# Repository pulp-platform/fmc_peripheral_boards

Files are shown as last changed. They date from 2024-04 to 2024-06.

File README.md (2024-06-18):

# FMC Peripheral Board

# Introduction

This repository contains the work on the FMC Peripheral boards, which are a set of PCB designs specifically created for validating peripherals on various FPGA platforms enhanced with the FPGA Mezzanine Card (FMC) standard.

In this repository, you will find source files and PDF schematics for a series of these PCB designs. These boards were developed with the specific purpose of facilitating peripheral verification of System on Chip (SoC) designs. We have put significant effort into ensuring these designs are robust and versatile, making them valuable tools for engineers who need to validate and test FPGA interfaces and achieve seamless integration with a wide range of peripheral devices. Moreover, thanks to the modularity of theese designs we have been able to test peripherals on silicon proven SoC managing to use the same hardware in the loop along the entire design process. By providing these resources, we aim to support the development and testing processes, allowing for more generic and broad applications.

Ideal for hardware developers and testers, these designs facilitate accurate and efficient verification processes, enhancing reliability and performance.

We have designed these PCBs to the best of our ability and they have performed well for us. However we offer no warranty of any kind (see also LICENSE) and provide these as is, without any support, use at your own risk.

# License

The files provided in this repository are released under Creative Commons with Attribution (`CC-BY`) (see `LICENSE` for details) license, except for `04_Expansion_Modules/USART_Module/fw/` that contains third-party source files that come from STMicroelectronics and has been released under Berkeley Software Distribution 3-Clause (`BSD 3-Clause`) license (see `04_Expansion_Modules/USART_Module/fw/LICENSE` for details).

# Structure of the repository

This repository contains the following folders:

- **`01_Carrier_Board`**
    - The described FMC (FPGA Mezzanine Card) Carrier board is designed to enhance FPGA development platforms by adding essential peripheral interfaces. This board is tailored for developers looking to experiment with and implement storage and audio functionalities in their FPGA projects.

    **Features of the FMC Board:**

    1. **Hyper Flash:**<br>
    The Hyper Flash provides high-speed non-volatile memory storage, ideal for applications requiring fast read and write operations with a high level of endurance. This makes it suitable for high-performance data buffering or quick-boot applications.

    2. **SPI Flash:**<br>
    The SPI Flash memory is included for reliable, low-latency access, serving as an excellent resource for storing firmware or small application codes in embedded systems. Its SPI interface ensures compatibility with a vast array of FPGA boards.

    3. **I2C EEPROM:**<br>
    Equipped with I2C EEPROM, this board offers a modest amount of memory but with very low power consumption, perfect for storing configuration settings or small amounts of data that must persist through power cycles, such as device calibration data or user preferences.

    4. **2x Microphones:**<br>
    The inclusion of two microphones allows for audio input and recording capabilities. This feature is especially useful for applications involving sound capture, voice command recognition, or environmental noise analysis. The dual setup can also support stereo audio recording or be used for advanced processing techniques like beamforming or noise reduction.

    **Design and Connectivity:**<br>
    The board is designed to conform to the FMC standard, ensuring it can be used with FMC-compatible FPGA development boards. It provides a high-pin-count (HPC) connector which allows it to interface seamlessly with the host FPGA, supporting high throughput and multiple I/O options.
    The board exposes 2x M.2 type E expansion connectors which allow to connect Expansion Module specifically designed for different targets

- **`02_FMC_Test_Module`**
    - The FMC test module described here is specifically designed for enhanced debugging and signal analysis.
    It can be attached directly on top of the carrier board to monitor and probe signals interfacing with various peripherals. It can also be configured to function as a GPIO (General Purpose Input/Output) expansion when connected directly to an FPGA, providing additional flexibility in signal management and control.

- **`03_Example_Module`**
    - This folder contains a design example of an M.2 type E expansion module

- **`04_Expansion_Modules`**
    - This folder contains the design of the following M.2 type E expansion modules

        - **`Ethernet_Module`**
            - The M.2 type E module described is a specialized network interface card (NIC) that incorporates Ethernet functionalities, specifically designed to fit into compact and modular systems. This module provides Ethernet connectivity via an RJ45 connector and features the RTL8211E-VL-CG Ethernet PHY transceiver, which supports various Ethernet standards including 10Base-T, 100Base-TX, and 1000Base-T as specified by the IEEE 802.3 standards.
            For data communication between the MAC (Media Access Control) layer and the PHY (Physical Layer), the module supports both RGMII (Reduced Gigabit Media Independent Interface) and GMII (Gigabit Media Independent Interface). RGMII is used for more compact and reduced pin count requirements, suitable for high-speed data operations at 1000Base-T, while GMII is applicable for full gigabit media independent data handling, including 1000Base-T, 10Base-T, and 100Base-TX.

        - **`PWM_Module`**
            - The M.2 type module described is an innovative expansion card specifically designed to test up to 8xPWM. It exposes four Crazyflie 2.X DC motor connectors which can be dinamically connected to all the PWM outputs.

        - **`USART_Module`**
            - The M.2 type module designed for communication with the STM32L412K8T6 microcontroller using the USART (Universal Synchronous/Asynchronous Receiver/Transmitter) protocol is a specialized interface card. This module serves as a bridge to facilitate robust serial communication between the design mapped on the FPGA and the onboard STM32L412K8T6 microcontroller. This folder is organized as follows:
               - `fw/`, directory contains source code dedicated to testing the USART functionality. To generate the complete software stack for the STM32L412K8T6 microcontroller, you can use the STM32 CubeMX Tool provided by STMicroelectronics (https://www.st.com/content/st_com/en/stm32cubemx.html#st-get-software) and configure its pinout accordingly to the schematic under `hw/Documentation/UART_Module_SCH.PDF`
               - `hw/`, directory contains the Altium designer source files and PDF schematics of the USART_Module

        - **`uSD_Module`**
            - The M.2 type module described is an innovative expansion card that facilitate the development, testing, and debugging of Secure Digital Input Output (SDIO) protocol implementations, allowing engineers to easily interface with microSD cards and ensure compliance with SDIO standards.

- **`05_FMC_4_Hyperram_32MB`**
    - The FMC board described here is a specialized module designed to significantly enhance the memory capabilities.
    It features four 8MB HyperRAMs, providing a total of 32MB of additional low-pin-count RAM. 

# Publications

If you use these PCBs in your work, please cite us:

```
@INPROCEEDINGS{9607006,
  author={Valente, Luca and Rossi, Davide and Benini, Luca},
  booktitle={2021 IFIP/IEEE 29th International Conference on Very Large Scale Integration (VLSI-SoC)}, 
  title={Hardware-In-The Loop Emulation for Agile Co-Design of Parallel Ultra-Low Power IoT Processors}, 
  year={2021},
  volume={},
  number={},
  pages={1-6},
  keywords={Program processors;Computational modeling;Emulation;Very large scale integration;Tools;Performance analysis;Sensors;Verification;FPGA emulation;IoT;CNN},
  doi={10.1109/VLSI-SoC53125.2021.9607006}}
```

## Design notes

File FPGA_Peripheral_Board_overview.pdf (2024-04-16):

# FPGA Peripheral Board

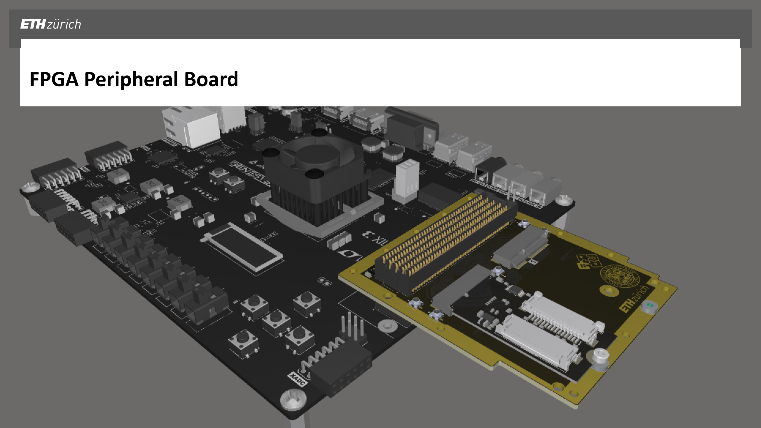
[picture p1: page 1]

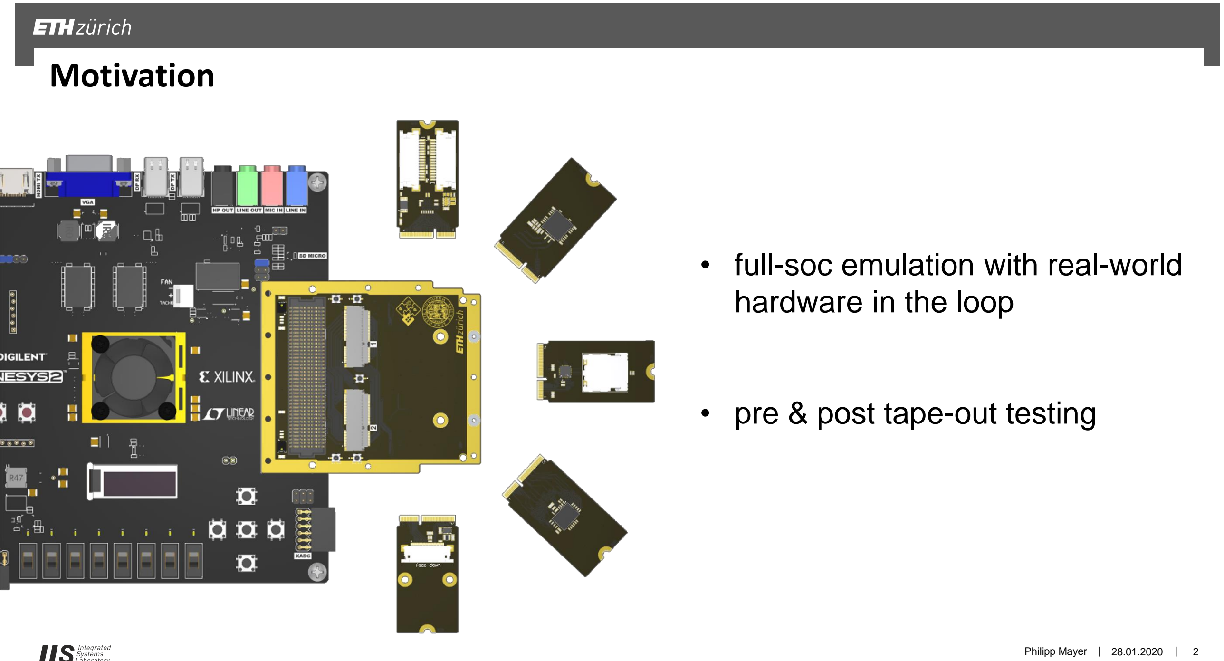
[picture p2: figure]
Philipp Mayer | 28.01.2020; Motivation; • full-soc emulation with real-world hardware in the loop; • pre & post tape-out testing

# Overview

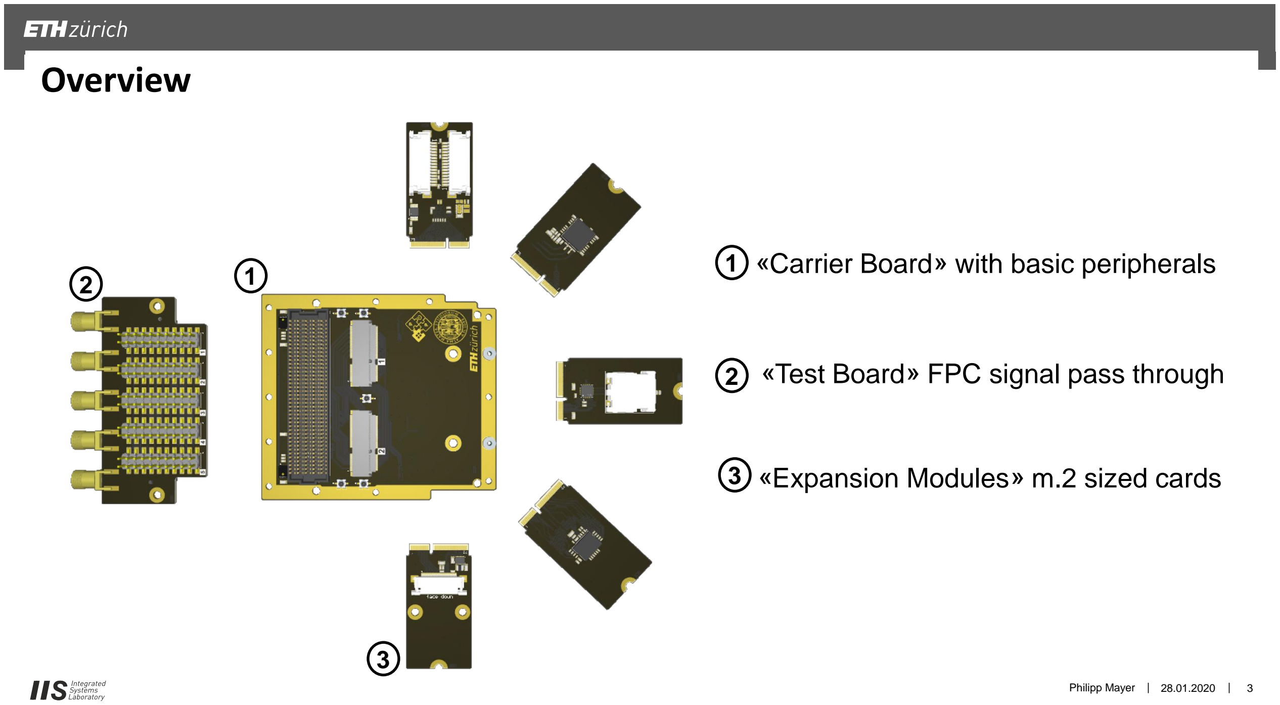
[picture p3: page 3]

# «Carrier Board» with basic peripherals 1

3

2

# «Test Board» FPC signal pass through

# «Expansion Modules» m.2 sized cards

1

2

3

# Block Diagram

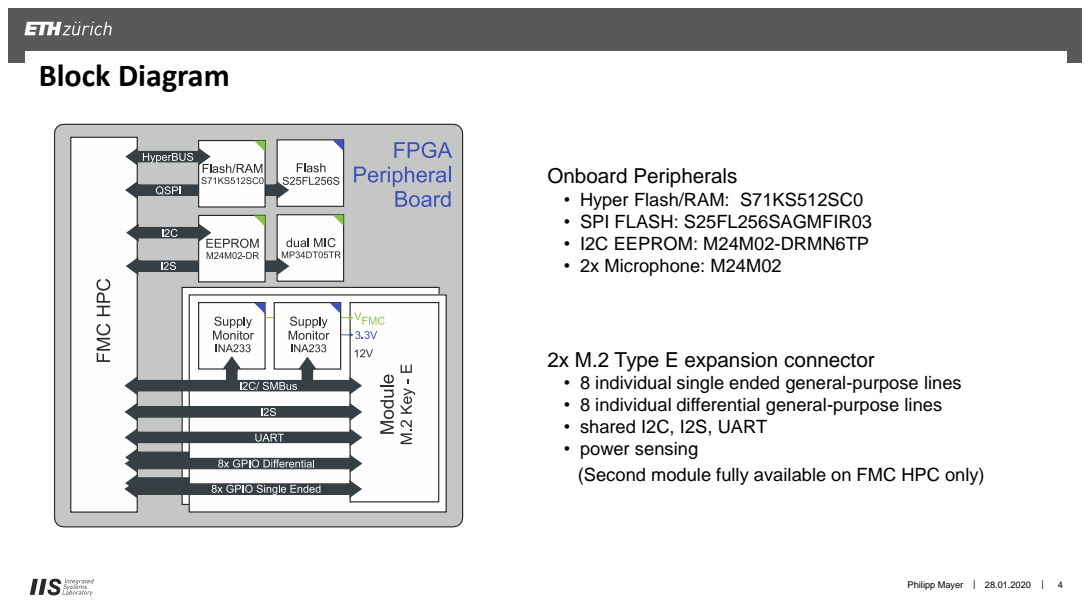
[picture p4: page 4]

Onboard Peripherals
• Hyper Flash/RAM: S71KS512SC0
• SPI FLASH: S25FL256SAGMFIR03
• I2C EEPROM: M24M02-DRMN6TP
• 2x Microphone: M24M02

2x M.2 Type E expansion connector
• 8 individual single ended general-purpose lines
• 8 individual differential general-purpose lines
• shared I2C, I2S, UART
• power sensing
(Second module fully available on FMC HPC only)

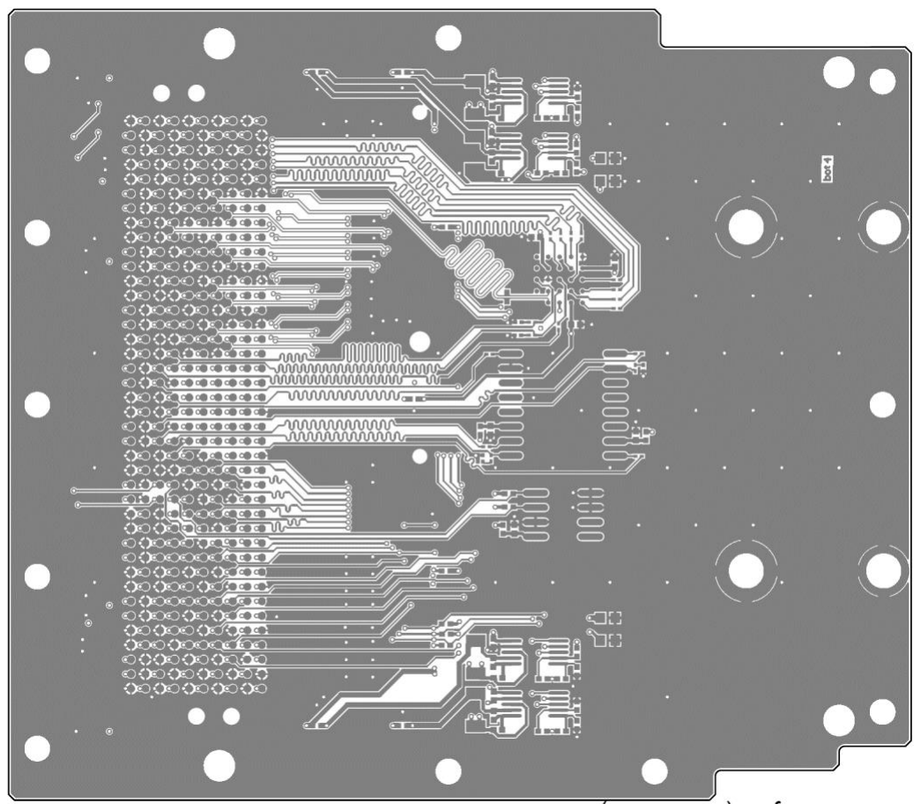
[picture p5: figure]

Signal Class | Routed Length | Delay Tolerance
HyperBUS | ~65 mm | 50 ps
QSPI | ~45 mm | 100 ps
CON1_GP_D[0..7 | ~50 mm | 50 ps
CON1_GP_S[0..7] | ~15 mm | 5 ps
CON2_GP_D[0..7] | ~14 mm | 50 ps
CON2_GP_S[0..7] | ~30 mm | 5 ps

# Only length matched

# in same signal group !

# Power Measurements

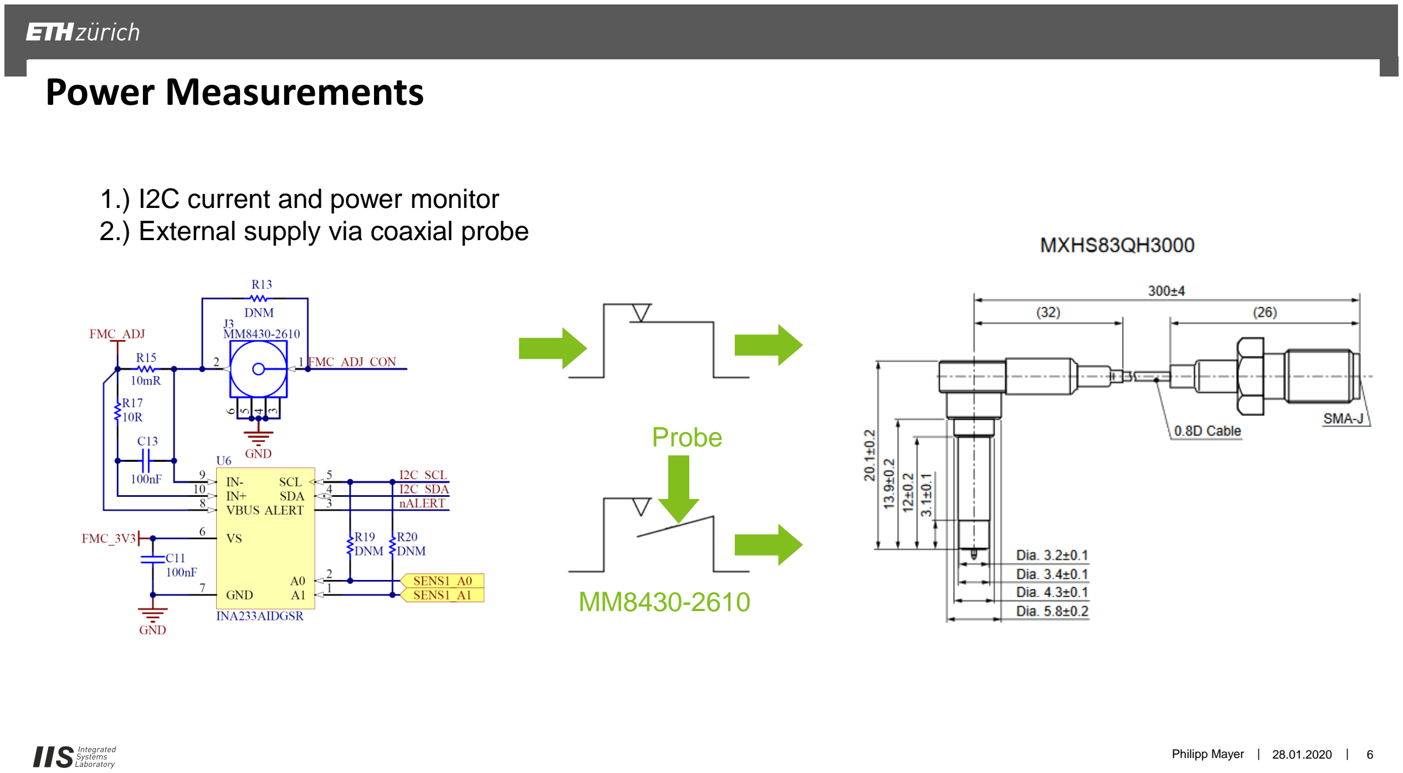
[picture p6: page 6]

# 1.) I2C current and power monitor 2.) External supply via coaxial probe

# Probe

MM8430-2610

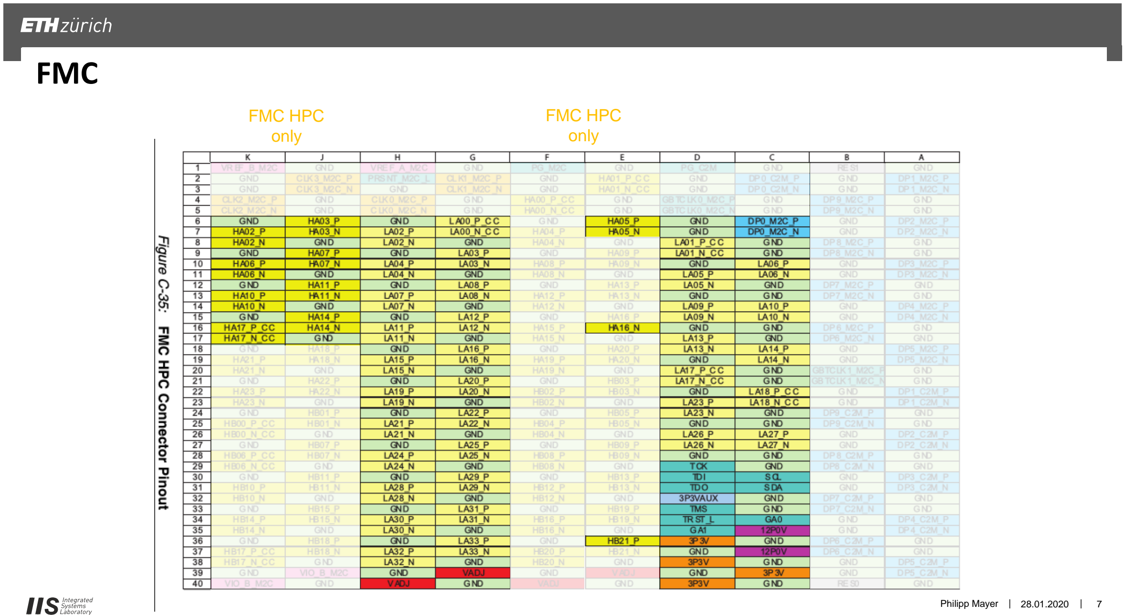
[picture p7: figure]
FMC; FMC HPC only

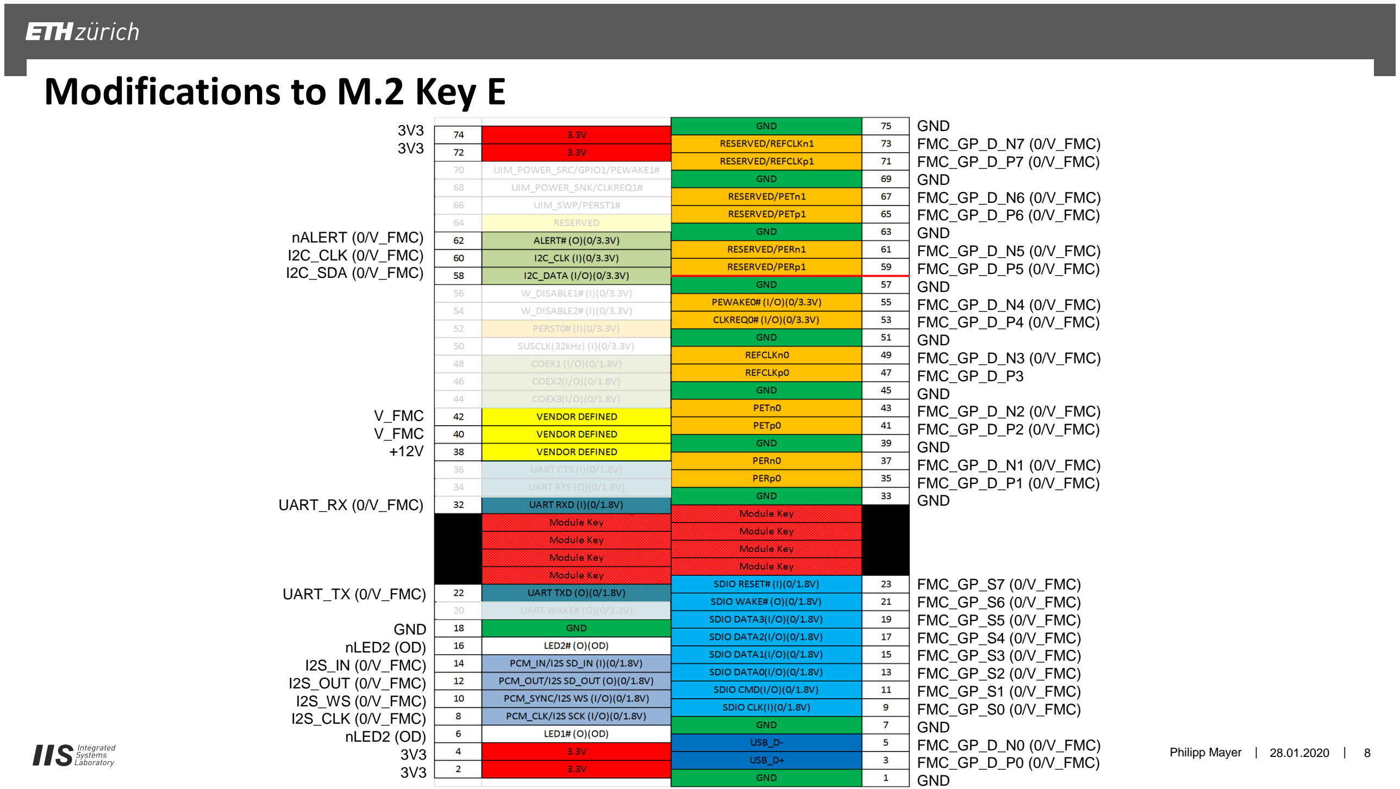
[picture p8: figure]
Modifications to M.2 Key E; GND FMC_GP_D_N7 (0/V_FMC) FMC_GP_D_P7 (0/V_FMC) GND FMC_GP_D_N6 (0/V_FMC) FMC_GP_D_P6 (0/V_FMC) GND FMC_GP_D_N5 (0/V_FMC) FMC_GP_D_P5 (0/V_FMC) GND FMC_GP_D_N4 (0/V_FMC) FMC_GP_D_P4 (0/V_FMC) GND FMC_GP_D_N3 (0/V_FMC) FMC_GP_D_P3 GND FMC_GP_D_N2 (0/V_FMC) FMC_GP_D_P2 (0/V_FMC) GND FMC_GP_D_N1 (0/V_FMC) FMC_GP_D_P1 (0/V_FMC) GND; FMC_GP_S7 (0/V_FMC) FMC_GP_S6 (0/V_FMC) FMC_GP_S5 (0/V_FMC) FMC_GP_S4 (0/V_FMC) FMC_GP_S3 (0/V_FMC) FMC_GP_S2 (0/V_FMC) FMC_GP_S1 (0/V_FMC) FMC_GP_S0 (0/V_FMC) GND FMC_GP_D_N0 (0/V_FMC) FMC_GP_D_P0 (0/V_FMC) GND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

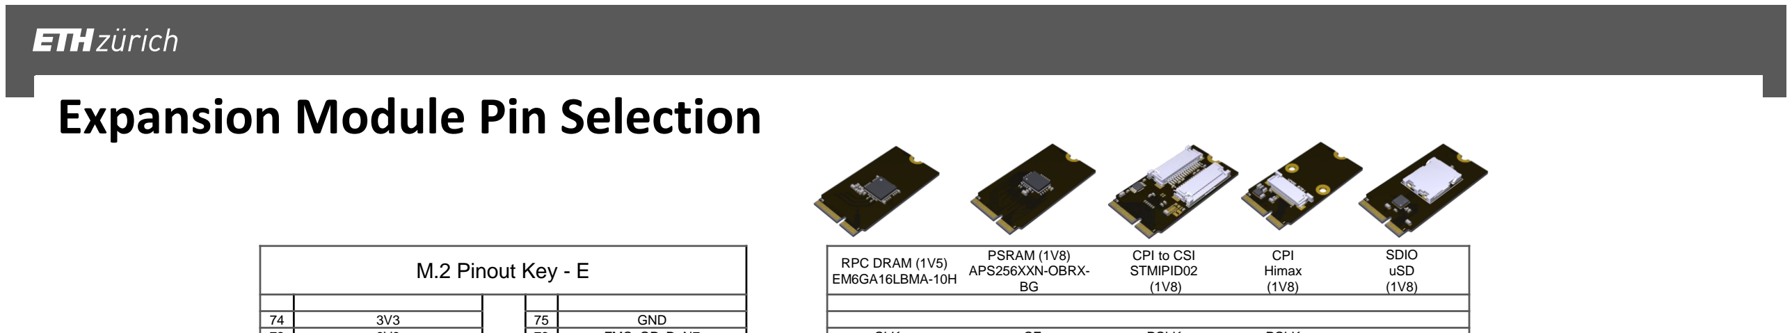
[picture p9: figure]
Expansion Module Pin Selection; M.2 Pinout Key - E; RPC DRAM (1V5) EM6GA16LBMA-10H; PSRAM (1V8) APS256XXN-OBRX- BG; CPI to CSI STMIPID02 (1V8); CPI Himax (1V8); SDIO uSD (1V8); GND

72 | 3V3 | 73 | FMC_GP_D_N7 | CLK_n | nCE | PCLK | PCLK
70 | RESERVED | 71 | FMC_GP_D_P7 | CLK_p | CK | | MCLK
68 | RESERVED | 69 | GND
66 | RESERVED | 67 | FMC_GP_D_N6 | DQS_n | DQS/DM1 | HSYNC | HSYNC
64 | RESERVED | 65 | FMC_GP_D_P6 | DQS_p | DQS/DM0 | VSYNC | VSYNC
62 | nALERT | 63 | GND
60 | I2C_SCL | 61 | FMC_GP_D_N5 | DQS1_n | | | INT
58 | I2C_SDA | 59 | FMC_GP_D_P5 | DQS1_p | | | TRIG
56 | RESERVED | 57 | GND
54 | RESERVED | 55 | FMC_GP_D_N4 | DB15 | DQ15
52 | RESERVED | 53 | FMC_GP_D_P4 | DB14 | DQ14
50 | RESERVED | 51 | GND
48 | RESERVED | 49 | FMC_GP_D_N3 | DB13 | DQ13
46 | RESERVED | 47 | FMC_GP_D_P3 | DB12 | DQ12
44 | RESERVED | 45 | GND
42 | FMC_ADJ (typ 1.8V) | 43 | FMC_GP_D_N2 | DB11 | DQ11 | D11
40 | FMC_ADJ (typ 1.8V) | 41 | FMC_GP_D_P2 | DB10 | DQ10 | D10
38 | FMC_12V | 39 | GND
36 | RESERVED | 37 | FMC_GP_D_N1 | DB9 | DQ9 | D9
34 | RESERVED | 35 | FMC_GP_D_P1 | DB8 | DQ8 | D8
32 | UART_RX | 33 | GND
30 | - | 31 | -
28 | - | 29 | -
26 | - | 27 | -
24 | - | 25 | -
22 | UART_TX | 23 | FMC_GP_S7 | DB7 | ADQ7 | D7 | D7
20 | RESERVED | 21 | FMC_GP_S6 | DB6 | ADQ6 | D6 | D6 | CLK RET
18 | GND | 19 | FMC_GP_S5 | DB5 | ADQ5 | D5 | D5 | SD_D3/nCS
16 | LED2 | 17 | FMC_GP_S4 | DB4 | ADQ4 | D4 | D4 | SD_D2
14 | I2S_IN | 15 | FMC_GP_S3 | DB3 | ADQ3 | D3 | D3 | SD_D1
12 | I2S_OUT | 13 | FMC_GP_S2 | DB2 | ADQ2 | D2 | D2 | SD_D0/MISO
10 | I2S_WS | 11 | FMC_GP_S1 | DB1 | ADQ1 | D1 | D1 | SD_CMD/MOSI
8 | I2S_CLK | 9 | FMC_GP_S0 | DB0 | ADQ0 | D0 | D0 | CLK/SCLK
6 | LED1 | 7 | GND
4 | 3V3 | 5 | FMC_GP_D_N0 | STB
2 | 3V3 | 3 | FMC_GP_D_P0 | nCS
| | 1 | GND

# * Not designed to reach peak DRAM speed!

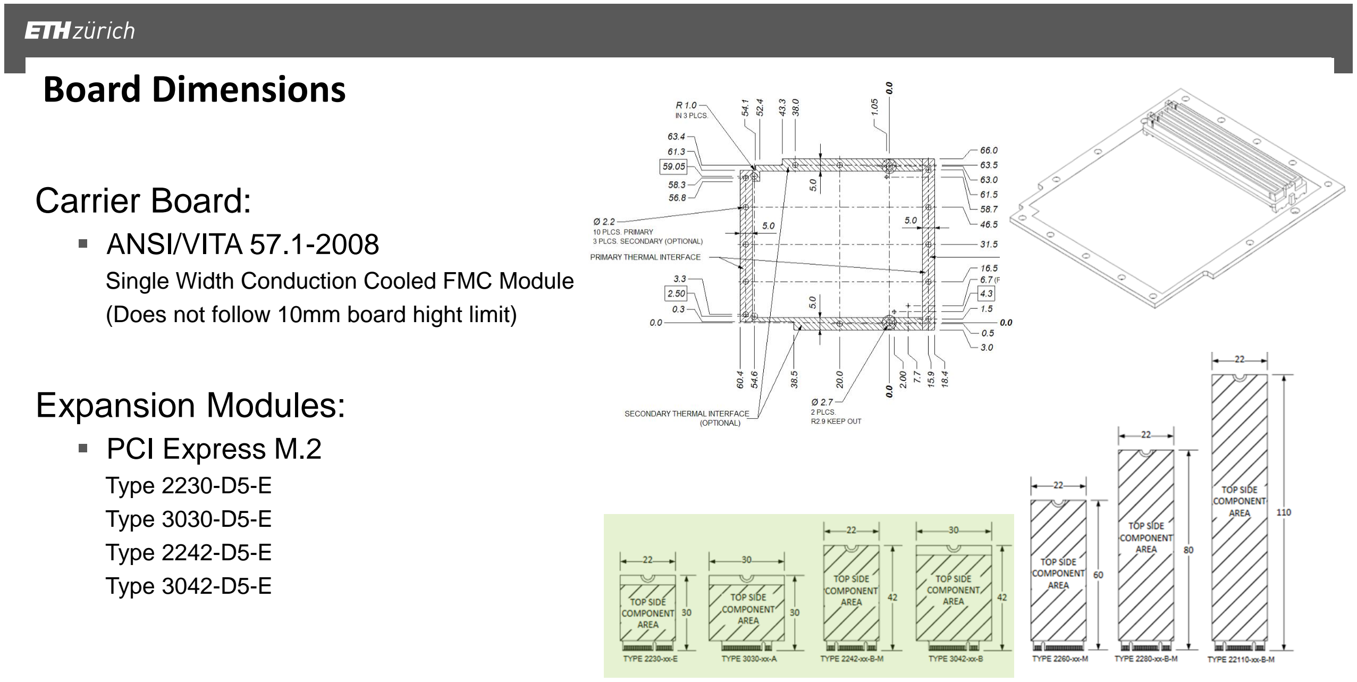
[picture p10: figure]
Board Dimensions; Carrier Board:; ▪ ANSI/VITA 57.1-2008; Expansion Modules:; ▪ PCI Express M.2; Type 2230-D5-E; Type 3030-D5-E; Type 2242-D5-E; Type 3042-D5-E

# Single Width Conduction Cooled FMC Module (Does not follow 10mm board hight limit)

# Documentation

“Conventional” board file | Supporting documentation

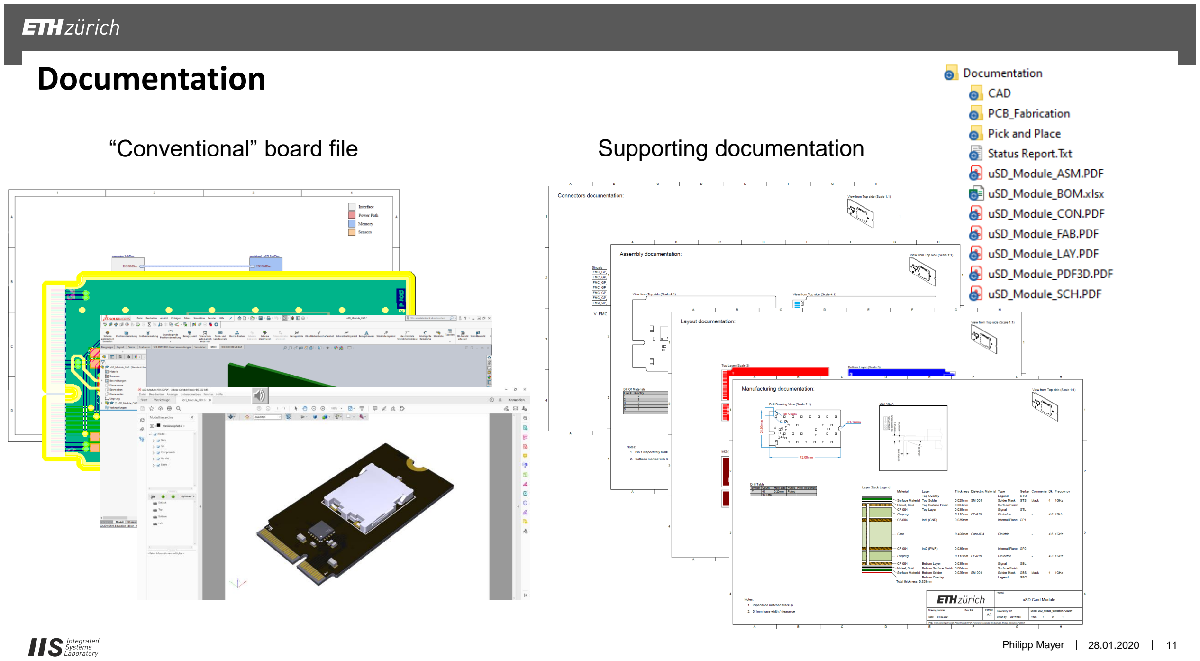
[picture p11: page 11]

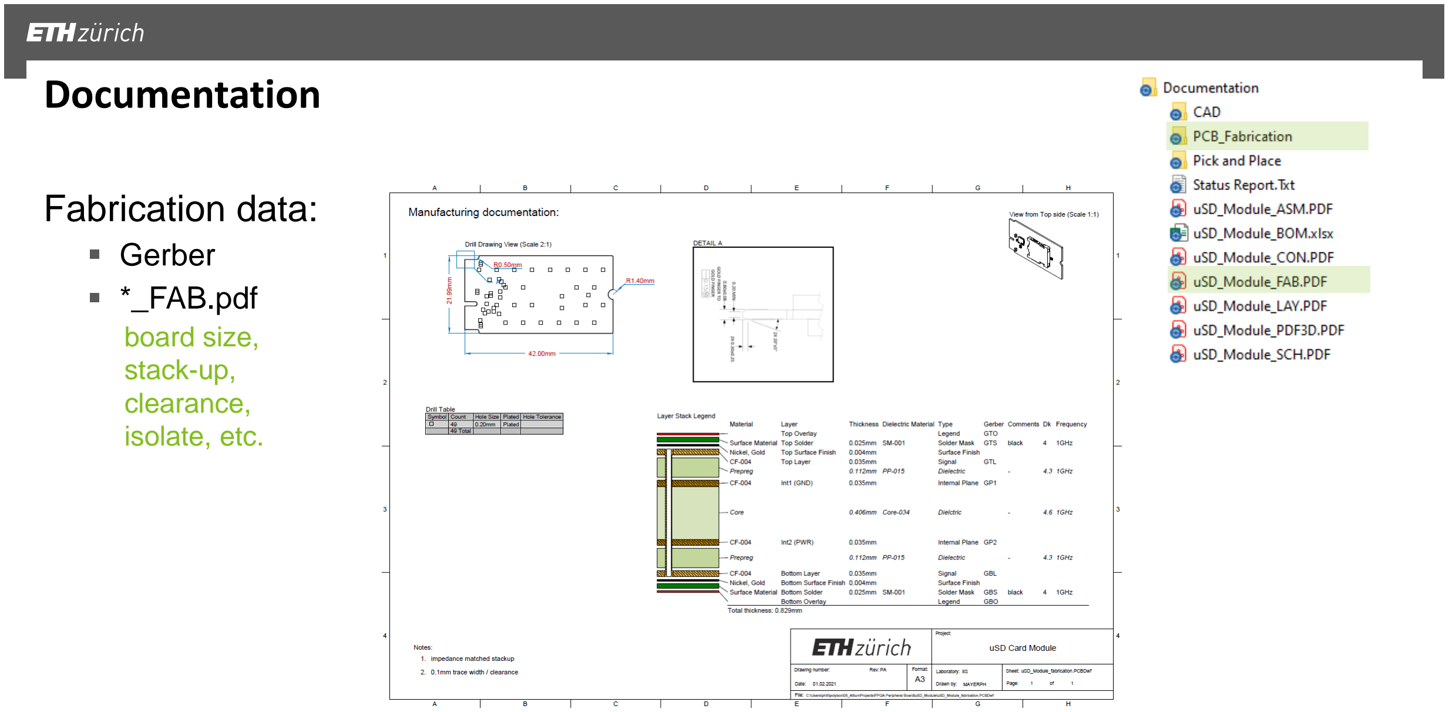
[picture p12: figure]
Fabrication data: ▪ Gerber ▪ *_FAB.pdf; Documentation; board size, stack; -up, clearance, isolate, etc.

Philipp Mayer | 28.01.2020 | 12

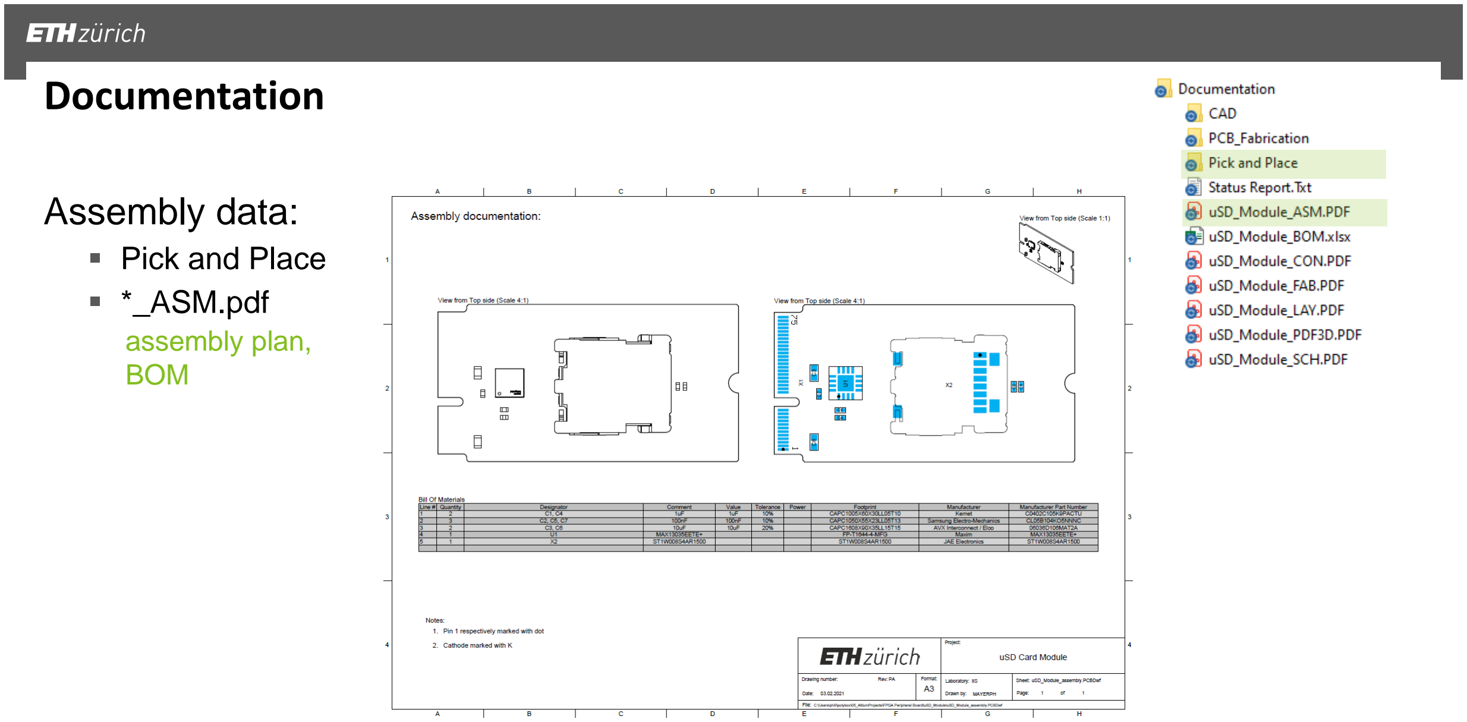
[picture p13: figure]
Assembly data:; ▪ Pick and Place ▪ *_ASM.pdf; Documentation; assembly plan, BOM

Philipp Mayer | 28.01.2020 | 13

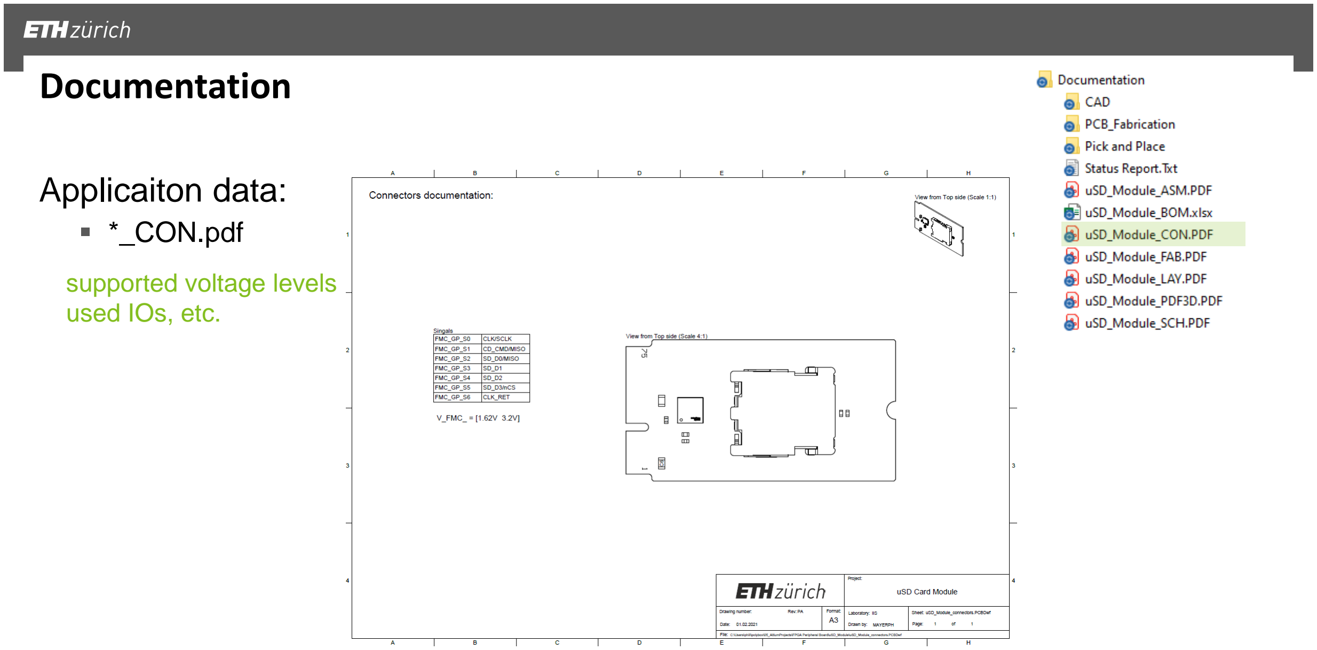
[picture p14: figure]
Applicaiton data:; ▪ *_CON.pdf; Documentation; supported voltage levels used IOs, etc.

Philipp Mayer | 28.01.2020 | 14

# - Modify the “Example Module” project

# Creating a New Module

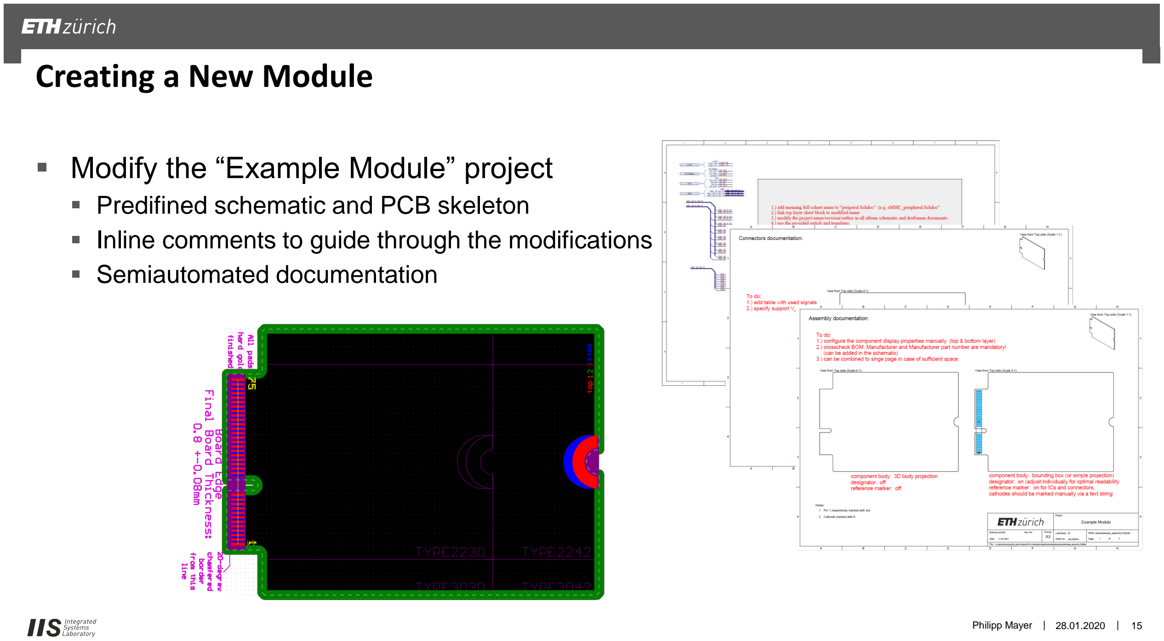
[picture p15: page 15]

# - Predifined schematic and PCB skeleton - Inline comments to guide through the modifications - Semiautomated documentation

Philipp Mayer | 28.01.2020 | 15

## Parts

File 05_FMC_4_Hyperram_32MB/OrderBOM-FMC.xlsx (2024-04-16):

Name | Notes | Description | Designator | Quantity | Manufacturer 1 | Manufacturer Part Number 1 | Supplier 1 | Supplier Part Number 1
ADP1715 |  | IC REG LINEAR 1.8V 500MA 8MSOP | ADP1715 | 1 | Analog Devices Inc | ADP1715ARMZ-1.8-R7 | Digi-key | ADP1715ARMZ-1.8-R7CT-ND
CAP 2.2 µF 25V 1206 (3216) |  | CAP 2.2 µF ±10% 25V X7R 1206 (3216 Metric) Thickness 1.80mm SMD | C13, C15 | 2 | TDK | C3216X7R1E225K160AA | Digi-key | 445-1382-1-ND
CAP 10nF 50V 1206 (3216) |  | CAP 10000pF ±10% 50V CH 1206 (3216 Metric) Thickness 0.75mm SMD | C14 | 1 | TDK | C3216CH1H103K060AA | Digi-key | 445-11579-1-ND
S71KS512SC0 |  | IC 512MB FLASH 64MB DRAM 24FBGA | U1, U2, U3, U4 | 4 | Cypress | S27KS0641DPBHI020 | Mouser | 727-S27KS0641DPBHI02
ASP-134604-01 |  | Conn Array Terminal FMC Male SKT 160 POS 1.27mm Solder ST SMD | J7 | 1 | Samtec | ASP-134604-01 | Digi-key | SAM8732-ND
15K 5% 0603(1608) | Do Not Place | 15K 0.1W 5% 0603 (1608 Metric) SMD | R1 | 1 | Bourns | CR0603-JW-153ELF | Digi-Key | 118-CR0603-JW-153ELFCT-ND
12K 5% 0603(1608) | Do Not Place | 12K 0.1W 5% 0603 (1608 Metric) SMD | R2 | 1 | Bourns | CR0603-JW-123ELF | Digi-Key | 118-CR0603-JW-123ELFCT-ND
CAP 100nF 25V 0603(1608) |  | CAP 100nF 25V ±10% 0603 (1608 Metric) Thickness 1mm SMD | C1, C2, C3, C4, C5, C6, C7, C8, C9, C10, C11, C12 | 12 | TDK | C1608X7R1E104K | Digi-Key | 445-1316-1-ND

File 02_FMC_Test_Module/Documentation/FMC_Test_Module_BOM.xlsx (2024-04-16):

Quantity | Designator | Comment | Value | Tolerance | Power | Footprint | Manufacturer | Manufacturer Part Number
1 | P1 | ASP-134488-01 |  |  |  | BTB-SM1-27-2V400M | Samtec | ASP-134488-01
5 | J1, J2, J3, J4, J5 | CON-SMA-EDGE-S |  |  |  | FP-CON-SMA-EDGE-S-MFG | RF Solutions Ltd. | CON-SMA-EDGE-S
5 | X1, X2, X3, X4, X5 | TSM-110-01-L-DV |  |  |  | SMTC-TSM-110-01-X-DV | Samtec | TSM-110-01-L-DV

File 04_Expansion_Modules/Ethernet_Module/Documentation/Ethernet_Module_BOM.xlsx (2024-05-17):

Quantity | Designator | Comment | Value | Tolerance | Power | Footprint | Manufacturer | Manufacturer Part Number | Supplier 1
3 | C1, C2, C10 | 1uF | 1uF | 10% |  | CAPC1005X60X30LL05T10 | Kemet | C0402C105K9PACTU | Digi-Key
3 | C6, C8, C9 | 10uF | 10uF | 20% |  | CAPC1608X90X35LL15T15 | AVX Interconnect / Elco | 06036D106MAT2A | Digi-Key
4 | C3, C4, C5, C7 | 100nF | 100nF | 10% |  | CAPC1050X55X23LL05T13 | Samsung Electro-Mechanics | CL05B104KO5NNNC | Digi-Key
3 | C11, C13, C14 | 27pF | 27pF | 5% |  | CAPC1005X56X25LL10T15 | KYOCERA AVX | 0402YA270JAT2A | mouser
1 | C12 | 1nF | 1nF | 1% |  | CAPC0603(1608)100_L | Vishay | VJ0603A102FXQCW1BC | mouser
9 | R1, R2, R3, R4 ,R6, R8, R9, R11, R14 | 4.7kR | 4.7kOhm | 1% |  | RESC0603X28X15LL05T05 | Vishay | CRCW02014K70FKED | mouser
1 | R10 | 75 R | 75 Ohm | 1% |  | RESC0603X28X15LL05T05 | Vishay | CRCW020175R0FKED | mouser
1 | R15 | 750 R | 750 Ohm | 1% |  | RESC0603X28X15LL05T05 | Vishay | CRCW0201750RFNED | mouser
1 | R7 | 1.5 kR | 1.5 kOhm | 1% |  | RESC0603X28X15LL05T05 | Vishay | CRCW04021K50FKED | mouser
1 | R13 | 2.49 kR | 2.49 kOhm | 1% |  | RESC0603X28X15LL05T05 | Vishay | CRCW02012K49FKED | mouser
1 | R12 | 1MegR | 1MOhm | 1% |  | RESC0603X28X15LL05T05 | Vishay | CRCW02011M00FKED | mouser
1 | R5 | 0R | 0 Ohm |  |  | RESC1005X40X25LL05T05 | Panasonic | ERJ-2GE0R00X | mouser
1 | LD1 | Yellow LEDs, Vf=1,65V |  |  |  |  | Kingbright | AA3021LSYSK/J3-TR | mouser
1 | LD2 | Red LEDs, Vf=1,8V |  |  |  | LEDC1608X65N | ROHM Semiconducto | CSL1901VW1 | mouser
1 | FB1 | BLM18KG601SN1B | 600Ohm/10MHz |  |  | BLM18EG121SH1D | Murata Electronics | BLM18KG601SN1B | mouser
1 | IC2 | RTL8211E-VL-CG |  |  |  | QFN40P600X600X100-49N |  | RTL8211E-VL-CG
1 | IC1 | LD39015M10R |  |  |  | SOT95P280X145-5N | STMicroelectronics | LD39015M10R | mouser
1 | Y1 | FL2500213Z |  |  |  |  | Diodes Incorporated | FL2500213Z | mouser
1 | J1 | HFJV1-E1G16-L12RL |  |  |  |  | HALO Electronics | HFJV1-E1G16-L12RL | mouser
2 | J2, J3 | HTSW-104-07-G-S |  |  |  |  | Samtec | HTSW-104-07-G-S | mouser

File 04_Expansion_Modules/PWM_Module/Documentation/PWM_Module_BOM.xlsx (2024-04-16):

Quantity | Comment | Designator | Description | Manufacturer | P/N | Supplier | Supplier P/N
4 | 22u | C1_1, C1_2, C1_3, C1_4 | Cap Ceramic 22uF 16V X5R ±20% Pad SMD 0603 +85°C T/R | Samsung | CL10A226MO7JZNC | Digi-Key | 1276-7076-1-ND
4 | PMEG4030ER,115 | D1_1, D1_2, D1_3, D1_4 | DIODE SCHOTTKY 40V 3A SOD123W | Nexperia USA Inc. | PMEG4030ER,115 | Digi-Key | 1727-5313-1-ND
4 | 53047-0210 | J1_1, J1_2, J1_3, J1_4 | CONN HEADER VERT 2POS 1.25MM | Molex | 0530470210 | Digi-Key | WM1731-ND
4 | 62200421121 | J2_1, J2_2, J2_3, J2_4 | THT Vertical Pin Header WR-PHD, Pitch 1.27 mm, Dual Row, 4 pins | Wurth Elektronik | 62200421121 | Digi-Key | 732-5372-ND
1 | TSW-202-07-G-S | J9 | CONN HEADER VERT 2POS 5.08MM | Samtec | TSW-202-07-G-S | Digi-Key | SAM13323-ND
1 | 2165713002 | J10 | Micro-Fit+ Vertical Header, Through Hole, 3.00mm Pitch, Single Row, 2 Circuits, 0.76µm Gold (Au) Plating, Glow-Wire Capable, Black | Molex | 2165713002 | Digi-Key | 900-2165713002-ND
4 | DMN2004K-7 | Q1_1, Q1_2, Q1_3, Q1_4 | MOSFET N-CH 20V 0.63A SOT23-3 | Diodes Inc. | DMN2024UQ-7 | Digi-Key | 31-DMN2024UQ-7CT-ND
4 | 10k | R1_1, R1_2, R1_3, R1_4 | Chip Resistor, 10 KOhm, +/- 1%, 0.1 W, -55 to 155 degC, 0603 (1608 Metric), RoHS, Tape and Reel | Panasonic | ERJ-3EKF1002V | Digi-Key | P10.0KHCT-ND
4 | 47R | R2_1, R2_2, R2_3, R2_4 | Chip Resistor, 47 Ohm, +/- 1%, 0.1 W, -55 to 155 degC, 0603 (1608 Metric), RoHS, Tape and Reel | Panasonic | ERJ-3EKF47R0V | Digi-Key | P47.0HCT-ND
1 | 0R | R9 | RES SMD 0 OHM JUMPER 1/10W 0603 | Panasonic | ERJ-3GEY0R00V | Digi-Key | P0.0GCT-ND
1 | 2157591002 | mates with J10 | Micro-Fit+ Receptacle Housing, Single Row, 2 Circuits, UL 94V-0, Glow-Wire Capable, Black | Molex | 2157591002 | Digi-Key | 900-2157591002-ND
2 | 2064600022 | crimps for 2157591002 | Micro-Fit+ Crimp Terminal, Female, 0.38µm Gold (Au) Plating, 20-24 AWG | Molex | 2064600022 | Digi-Key | 900-2064600022CT-ND
4 | 62200213421 | bridge for J2 connectors | WR-PHD 1.27 mm Jumper 1x2 | Wurth Elektronik | 62200213421 | Digi-Key | 732-13628-ND

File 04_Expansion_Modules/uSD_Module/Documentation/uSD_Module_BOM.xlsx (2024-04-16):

Quantity | Designator | Comment | Value | Tolerance | Power | Footprint | Manufacturer | Manufacturer Part Number | Supplier | Supplier Part Number
1 | U1 | MAX13035EETE+ |  |  |  | FP-T1644-4-MFG | Maxim | MAX13035EETE+ | Digi-Key | MAX13035EETE+-ND
1 | X2 | ST1W008S4AR1500 |  |  |  | ST1W008S4AR1500 | JAE Electronics | ST1W008S4AR1500 | Digi-Key | 670-2921-1-ND
2 | C1, C4 | 1uF | 1uF | 10% |  | CAPC1005X60X30LL05T10 | Kemet | C0402C105K9PACTU | Digi-Key | 399-C0402C105K9PAC7867CT-ND
2 | C3, C6 | 10uF | 10uF | 20% |  | CAPC1608X90X35LL15T15 | AVX Interconnect / Elco | 06036D106MAT2A | Digi-Key | 478-5318-1-ND
3 | C2, C5, C7 | 100nF | 100nF | 10% |  | CAPC1050X55X23LL05T13 | Samsung Electro-Mechanics | CL05B104KO5NNNC | Digi-Key | 1276-1001-1-ND

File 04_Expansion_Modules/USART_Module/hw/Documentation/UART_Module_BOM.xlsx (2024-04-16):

Comment | Description | Designator | Quantity | Manufacturer | P\N | Supplier | Supplier P/N
100R | RES Thick Film, 100Ω, 5%, 0.1W, 200ppm/°C, 0603 | R1, R2, R3, R4, R5, R6, R7, R8 | 8 | Panasonic Electronic Components | ERJ-3EKF1000V | Digi-Key | P100HCT-ND
4u7 | Multilayer Ceramic Capacitors 4.7μF ±10% 16V X7R SMD 0603 | C1, C5, C10, C11, C12, C13 | 6 | Murata Electronics | GRM188Z71C475KE21D | Digi-Key | 490-GRM188Z71C475KE21DCT-ND
100n | Multilayer Ceramic Capacitors 100nF ±10% 16V X7R SMD 0603 | C2, C4, C6, C9 | 4 | KEMET | C0603C104K4RAC7867 | Digi-Key | 399-C0603C104K4RAC7867CT-ND
BSS806 | MOSFET N-CH 20V 2.3A SOT23-3 | Q1, Q2, Q3, Q4 | 4 | Infineon Technologies | BSS806NEH6327XTSA1 | Digi-Key | BSS806NEH6327XTSA1CT-ND
Green | LED GREEN CLEAR 0603 SMD | LD1, LD2, LD3, LD4 | 4 | Wurth Elektronik | 150060VS75003 | Digi-Key | 732-150060VS75003CT-ND
1u | Multilayer Ceramic Capacitors 1μF ±10% 16V X7R SMD 0603 | C3 | 1 | KEMET | C0603C105K4RAC7411 | Digi-Key | 399-C0603C105K4RAC7411CT-ND
61300411121 | THT Vertical Pin Header WR-PHD, Pitch 2.54 mm, Single Row, 4 pins | P4 | 1 | Wurth Elektronik | 61300411121 | Digi-Key | 732-5317-ND
61300511121 | THT Vertical Pin Header WR-PHD, Pitch 2.54 mm, Single Row, 5 pins | P3 | 1 | Wurth Elektronik | 61300511121 | Digi-Key | 732-5318-ND
61301421121 | THT Vertical Pin Header WR-PHD, Pitch 2.54 mm, Dual Row, 14 pins | P2 | 1 | Wurth Elektronik | 61301421121 | Digi-Key | 732-5298-ND
62201021121 | THT Vertical Pin Header WR-PHD, Pitch 1.27 mm, Dual Row, 10 pins | P1 | 1 | Wurth Elektronik | 62201021121 | Digi-Key | 732-5374-ND
KMR231GLFS | SWITCH TACTILE SPST-NO 0.05A 32V | SW1 | 1 | C&K | KMR231GLFS | Digi-Key | 401-1429-1-ND
S-1172B18-E6T1U | LDO 1V8 fixed | U3 | 1 | ABLIC Inc. | S-1172B18-E6T1U | Digi-Key | 1662-1402-1-ND
STM32L412K8T6 | MCU 32-bit | U1 | 1 | STMicroelectronics | STM32L412K8T6 | Digi-Key | 497-STM32L412K8T6-ND

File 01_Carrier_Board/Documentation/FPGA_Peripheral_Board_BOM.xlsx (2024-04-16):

Quantity | Designator | Comment | Value | Tolerance | Power | Footprint | Manufacturer | Manufacturer Part Number
1 | J1 | ASP-134486-01 |  |  |  | BTB-SM1-27-2V400F | Samtec | ASP-134486-01
1 | P1 | ASP-134488-01 |  |  |  | BTB-SM1-27-2V400M | Samtec | ASP-134488-01
1 | R7 | 10k | 10 kOhm | 1% |  | RESC1005X40X25LL05T10 | Yageo / Phycomp | RC0402FR-0710KL
1 | R32 | 100R | 100 Ohm | 1% |  | RESC0603X28X15ML05T05 | Vishay | CRCW0201100RFKED
1 | U3 | S71KS512SC0 |  |  |  | FBGA24_A-130 | Cypress Semiconductor Corp | S71KS512SC0BHV000
1 | U4 | M24M02-DRMN6TP |  |  |  | M08A_N | STMicroelectronics | M24M02-DRMN6TP
1 | U5 | S25FL256SAGMFIR03 |  |  |  | SOIC127P1030X265-16N | Cypress Semiconductor Corp | S25FL256SAGMFIR03
2 | C1, C3 | 1uF | 1uF | 10% |  | CAPC1005X60X30LL05T10 | Kemet | C0402C105K9PACTU
2 | M2_CON1, M2_CON2 | 9774015243R |  |  |  | 9774015243R | Wurth Electronics | 9774015243R
2 | U1, U2 | MP34DT05TR-A |  |  |  | FP-HCLGA-DM00231908-MFG | STMicroelectronics | MP34DT05TR-A
2 | X1_CON1, X1_CON2 | 2199119-4 |  |  |  | 2199119-4 | TE Connectivity | 2199230-4
4 | C23, C24, C25, C26 | 100pF | 100pF | 10% |  | CAPC0603X33X15LL03T05 | AVX Interconnect / Elco | 0201YC101KAT2A
4 | R3, R4, R5, R6 | 2k2 | 2.2 kOhm | 1% |  | RESC1005X40X25LL05T10 | Yageo / Phycomp | RC0402FR-072K2L
4 | R15_CON1, R15_CON2, R16_CON1, R16_CON2 | 10mR | 10 mOhm | 1% |  | RESC3116X65X40NL10T20 | Yageo | RL1206FR-070R01L
4 | R17_CON1, R17_CON2, R18_CON1, R18_CON2 | 10R | 10 Ohm | 1% |  | RESC1005X40X25LL10T10 | Bourns | CR0402-FX-10R0GLF
4 | U6_CON1, U6_CON2, U7_CON1, U7_CON2 | INA233AIDGSR |  |  |  | ADI-RM-10_N | Texas Instruments | INA233AIDGSR
5 | J2, J3_CON1, J3_CON2, J4_CON1, J4_CON2 | MM8430-2610 |  |  |  | MM8430-2610 | Murata | MM8430-2610RA1
8 | C15, C16, C17, C18, C19, C20, C21, C22 | 10uF | 10uF | 20% |  | CAPC1608X90X35LL15T15 | AVX Interconnect / Elco | 06036D106MAT2A
15 | R1, R2, R9, R10, R11, R12_CON1, R12_CON2, R23, R24, R25, R26, R27, R28, R29, R30 | 0R | 0 Ohm | 5% |  | RESC1005X40X25LL05T10 | Yageo | RC0402JR-070RL
16 | C2, C4, C5, C6, C7, C8, C9, C10, C11_CON1, C11_CON2, C12_CON1, C12_CON2, C13_CON1, C13_CON2, C14_CON1, C14_CON2 | 100nF | 100nF | 10% |  | CAPC1050X55X23LL05T13 | Samsung Electro-Mechanics | CL05B104KO5NNNC
17 | R31, R33, R34, R35, R36, R37, R38, R39, R40, R41, R42, R43, R44, R45, R46, R47, R48 | 49.9R | 49.9 Ohm | 1% |  | RESC0603X26X15LL03T05 | Panasonic | ERJ-1GEF49R9C

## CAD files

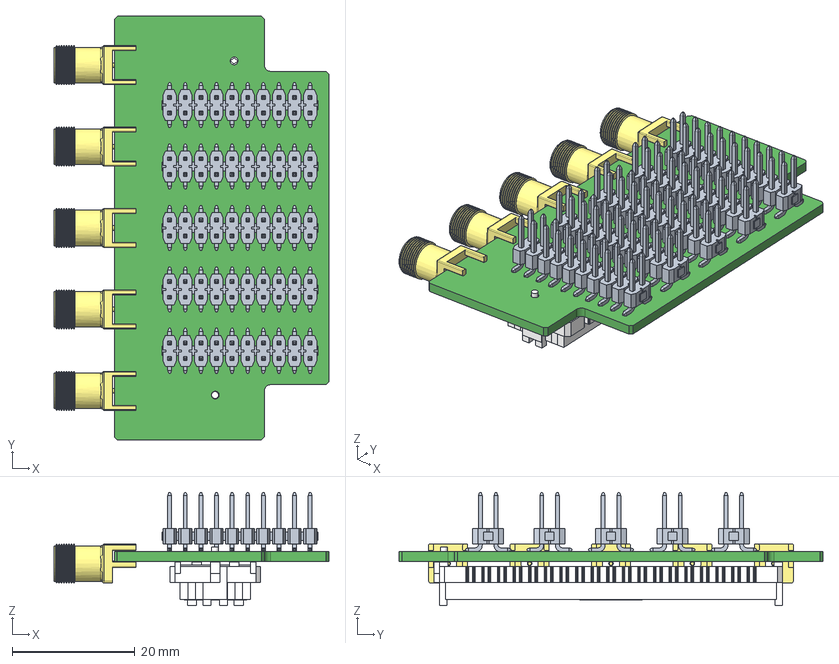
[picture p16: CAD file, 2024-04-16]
02_FMC_Test_Module/Documentation/CAD/FMC_Test_Module_CAD.step
44.8 x 69.0 x 18.4 mm
TSM-110-01-X-DV x 5
Extruded x 30

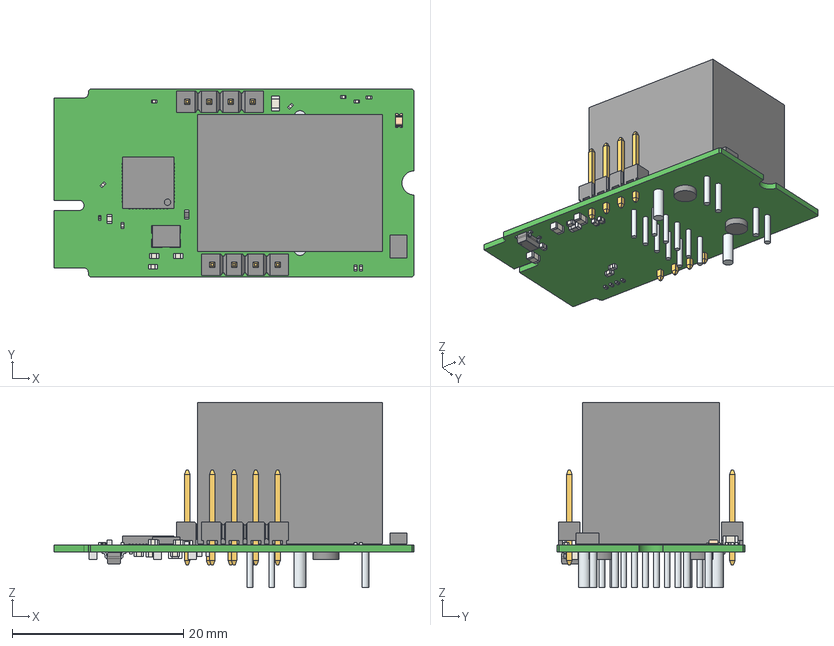
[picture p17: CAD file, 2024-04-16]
04_Expansion_Modules/Ethernet_Module/Documentation/CAD/ETH_Module_CAD.step
42.0 x 22.0 x 21.6 mm
Lugs
Leads
HTSW-104-07-G-S_body x 2
logo x 2
terminal x 8
Extruded x 81
CSL19_2
CSL19_3
CSL19_4
CSL19
CSL19_5
Pins x 2
Mid_Body
Open_CASCADE_STEP_translator_6.8_9.2.1 x 2
Mark
term1
term2
ThermalPin
PinsArrayLR
PinsArrayTB
PinsArrayL
PinsArrayR

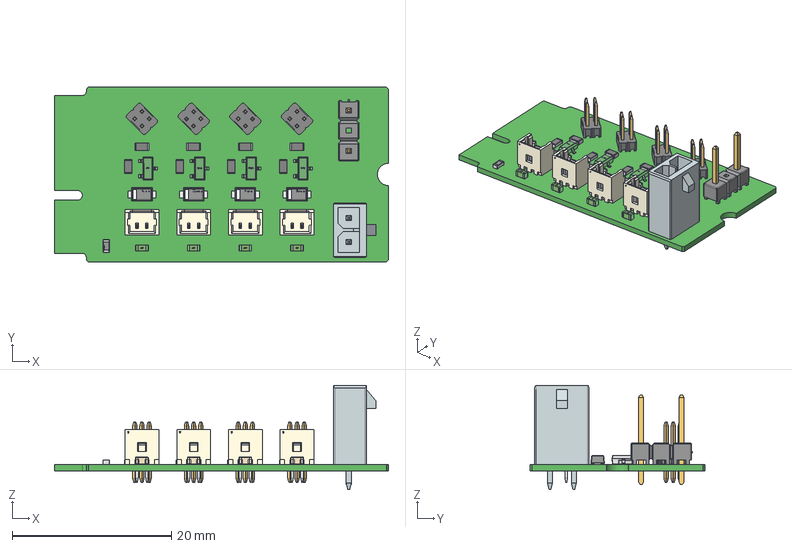
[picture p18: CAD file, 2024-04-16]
04_Expansion_Modules/PWM_Module/Documentation/CAD/PWM_Module_CAD.step
42.0 x 22.0 x 13.1 mm
IC_BODY x 4
IC_LEG x 12
Diodes Incorporated x 4
Nexperia Logo x 4
_TSW-202-07-G-S_body
_T-1S6-07-TSW-2-07-2-S
Samtec Logo
622xxx21121_Pin x 16
622x0421121_Housing x 4
Mid_Body x 8
Mark x 8
Pins x 4
Molex_Logo x 4
Marking x 4
Samsung logo x 4
Pieza60
Pieza63
Pieza64
Pieza65

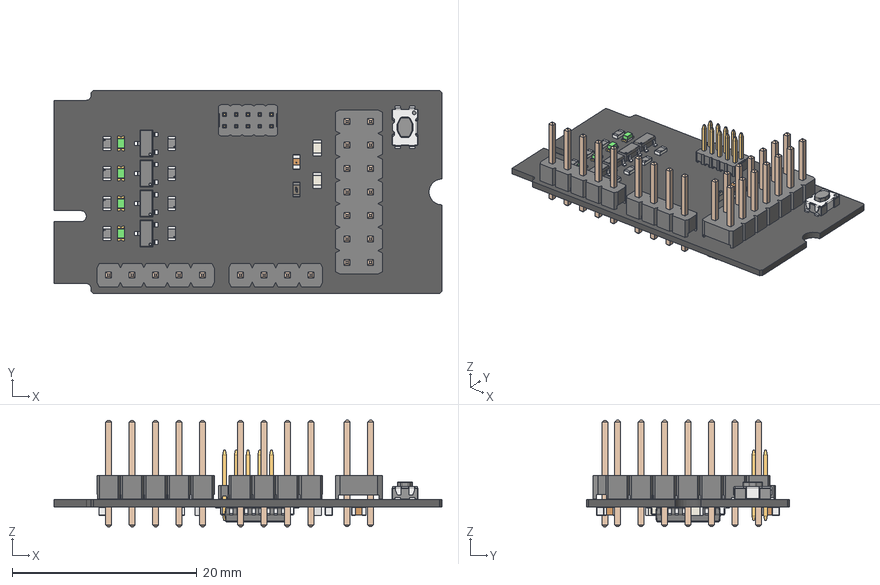
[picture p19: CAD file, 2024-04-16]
04_Expansion_Modules/USART_Module/hw/Documentation/CAD/UART_Module_CAD.step
42.0 x 22.0 x 11.6 mm
Pads x 6
TDK_Logo x 6
6130xx11121_PIN x 9
Vishay logo - Copy x 8
Vishay logo x 8
Extruded x 12
Samsung logo
FAIR-SSOT3L-3_V x 4
6130xx21121_PIN x 14
pin 1
logo
shield
base x 9
terminals
housing x 4
cover x 4
Polarity Mark x 4
Mark x 4
Leader x 32
622xxx21121_Pin x 10
622x1021121_Housing

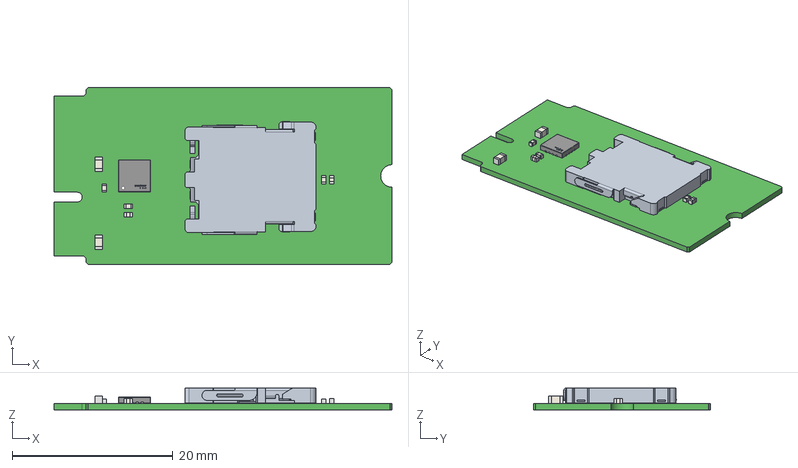
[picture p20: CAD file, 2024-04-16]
04_Expansion_Modules/uSD_Module/Documentation/CAD/uSD_Module_CAD.step
42.0 x 22.0 x 2.73 mm
Extruded x 21
Maxim_MAX13035EETE+_2
Maxim_MAX13035EETE+_1
Maxim_Integrated_Logo___
K3D-ST1W008S4A-R2_JAE_Connector_Division_Proprietary

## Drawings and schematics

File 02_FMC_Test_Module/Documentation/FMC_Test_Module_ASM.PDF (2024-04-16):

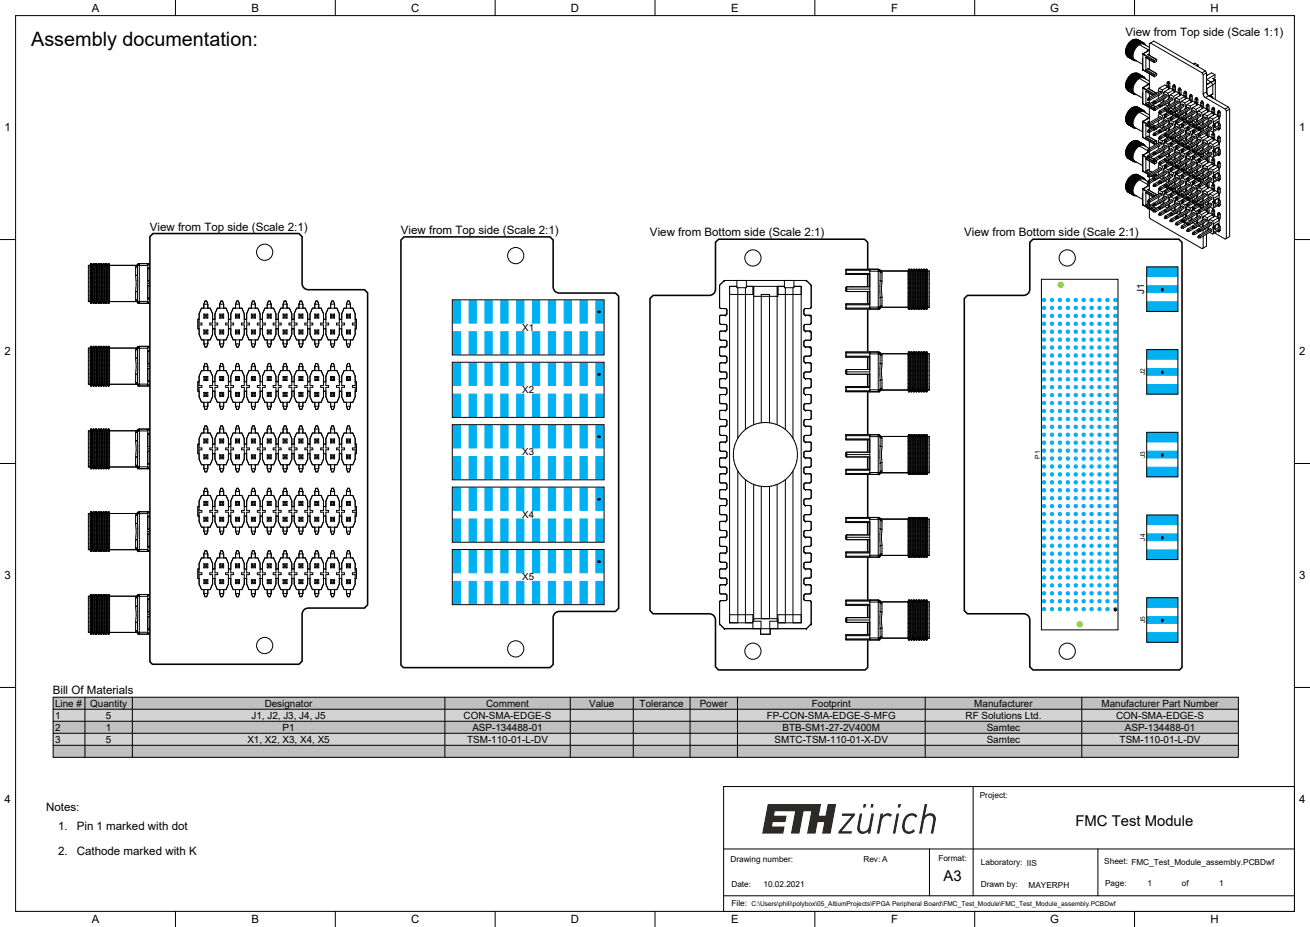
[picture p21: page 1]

View from Top side (Scale 1:1)

View from Top side (Scale 2:1)

View from Bottom side (Scale 2:1)

FP-CON-SMA-EDGE-S-MFG
BTB-SM1-27-2V400M
SMTC-TSM-110-01-X-DV

Notes:
1. Pin 1 marked with dot

File:
C:\Users\phili\polybox\05_AltiumProjects\FPGA Peripheral Board\FMC_Test_Module\FMC_Test_Module_assembly.PCBDwf

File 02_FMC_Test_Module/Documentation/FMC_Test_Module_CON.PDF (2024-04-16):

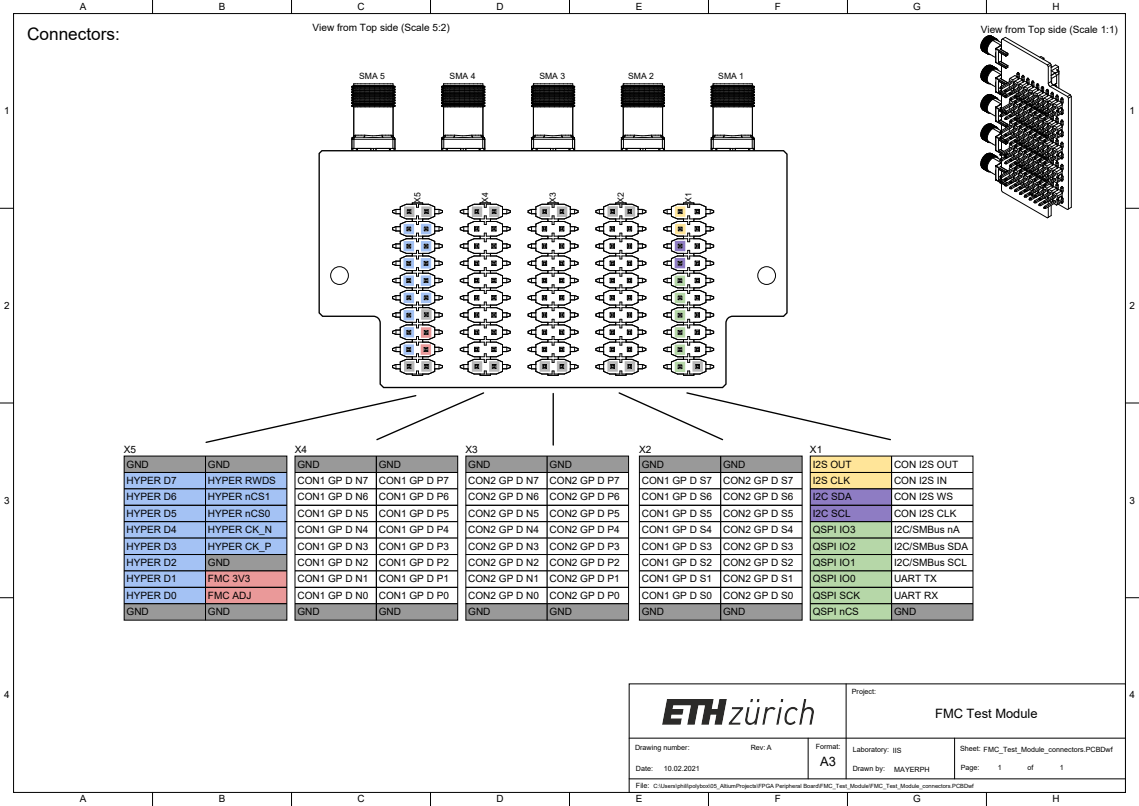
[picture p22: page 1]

File:
C:\Users\phili\polybox\05_AltiumProjects\FPGA Peripheral Board\FMC_Test_Module\FMC_Test_Module_connectors.PCBDwf

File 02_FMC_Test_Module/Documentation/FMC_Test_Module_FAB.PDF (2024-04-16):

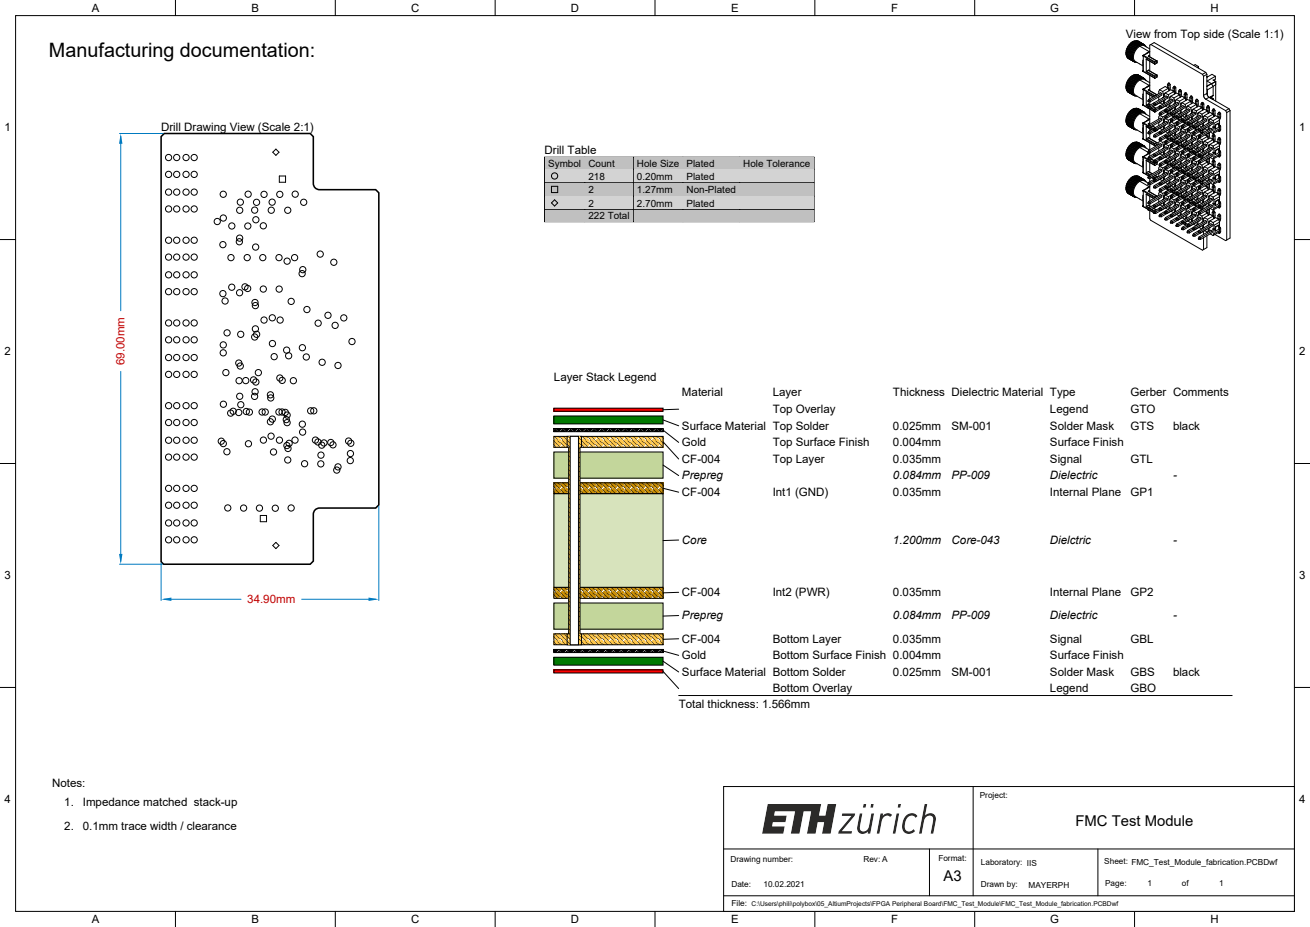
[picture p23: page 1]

View from Top side (Scale 1:1)

Drill Drawing View (Scale 2:1)

Symbol | Count | Hole Size | Plated | Hole Tolerance

218 | 0.20mm | Plated
2 | 1.27mm | Non-Plated
2 | 2.70mm | Plated
222 Total

Notes:
1. Impedance matched stack-up

File:
C:\Users\phili\polybox\05_AltiumProjects\FPGA Peripheral Board\FMC_Test_Module\FMC_Test_Module_fabrication.PCBDwf

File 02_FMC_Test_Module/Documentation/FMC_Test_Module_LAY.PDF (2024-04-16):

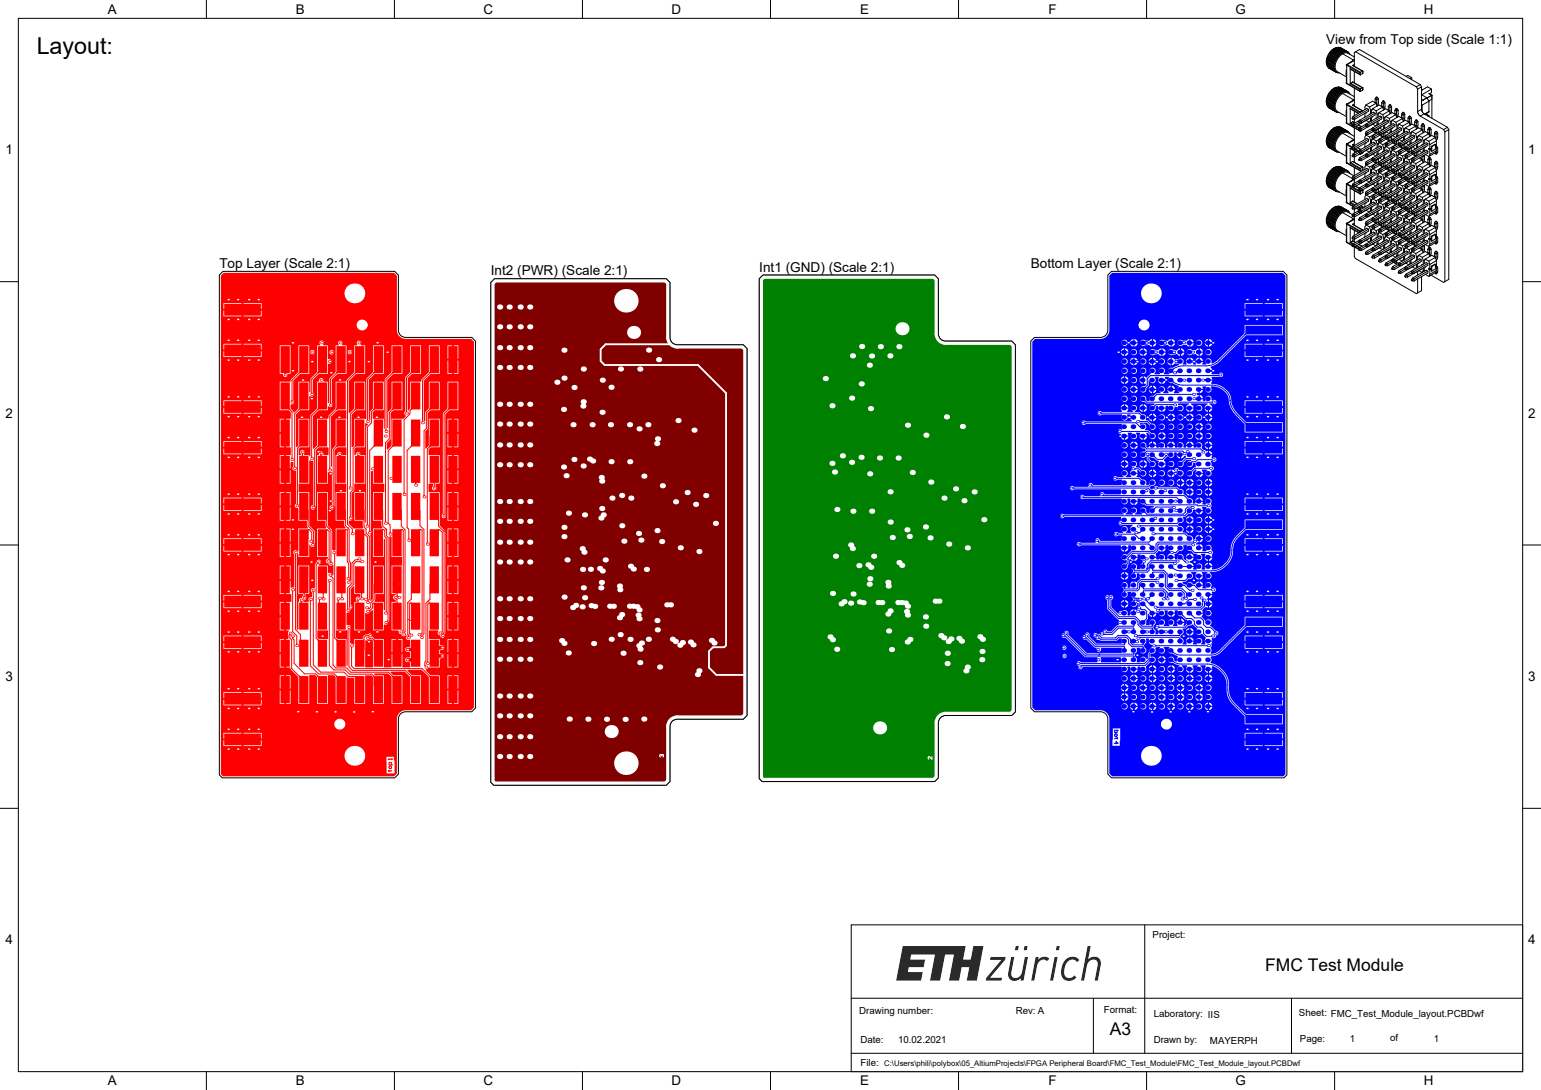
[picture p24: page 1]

View from Top side (Scale 1:1)

Project: FMC Test Module

Drawing number: Rev: A Date: 10.02.2021 | Format: | Laboratory: IIS Drawn by: MAYERPH | Sheet: FMC_Test_Module_layout.PCBDwf of A3 Page: 1 1

File:
C:\Users\phili\polybox\05_AltiumProjects\FPGA Peripheral Board\FMC_Test_Module\FMC_Test_Module_layout.PCBDwf

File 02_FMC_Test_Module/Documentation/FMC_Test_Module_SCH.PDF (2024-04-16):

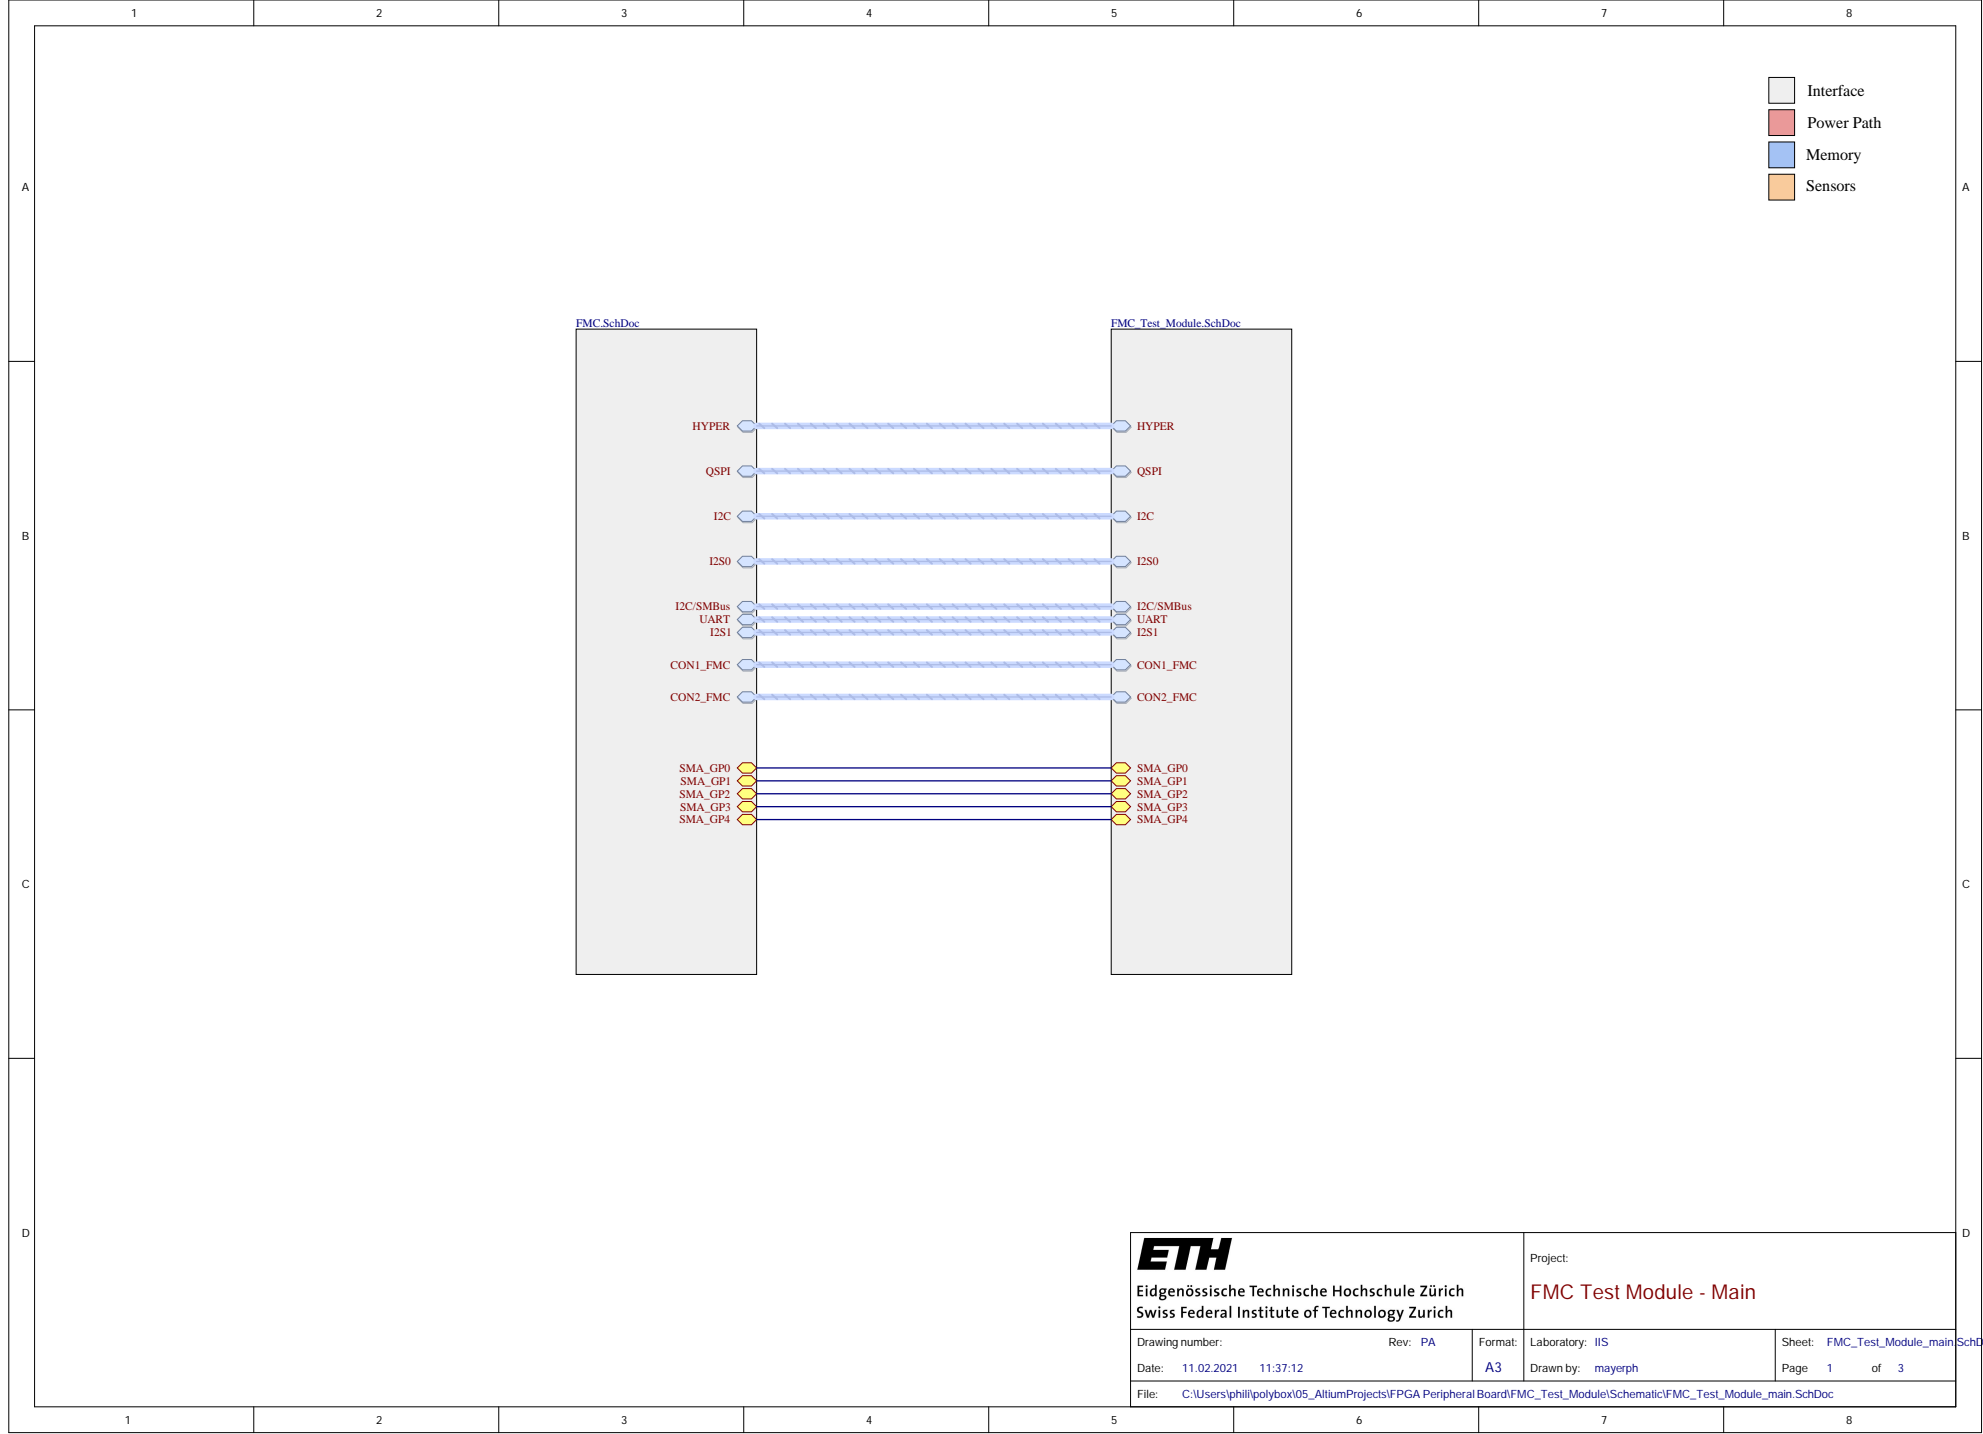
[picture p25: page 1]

FMC.SchDoc FMC_Test_Module.SchDoc

Project: FMC Test Module - Main

Drawing number: Rev: PA Date: 11.02.2021 11:37:12 | Format: A3 | Laboratory: IIS Drawn by: mayerph | Sheet: Page 1 of 3

C:\Users\phili\polybox\05_AltiumProjects\FPGA Peripheral Board\FMC_Test_Module\Schematic\FMC_Test_Module_main.SchDoc

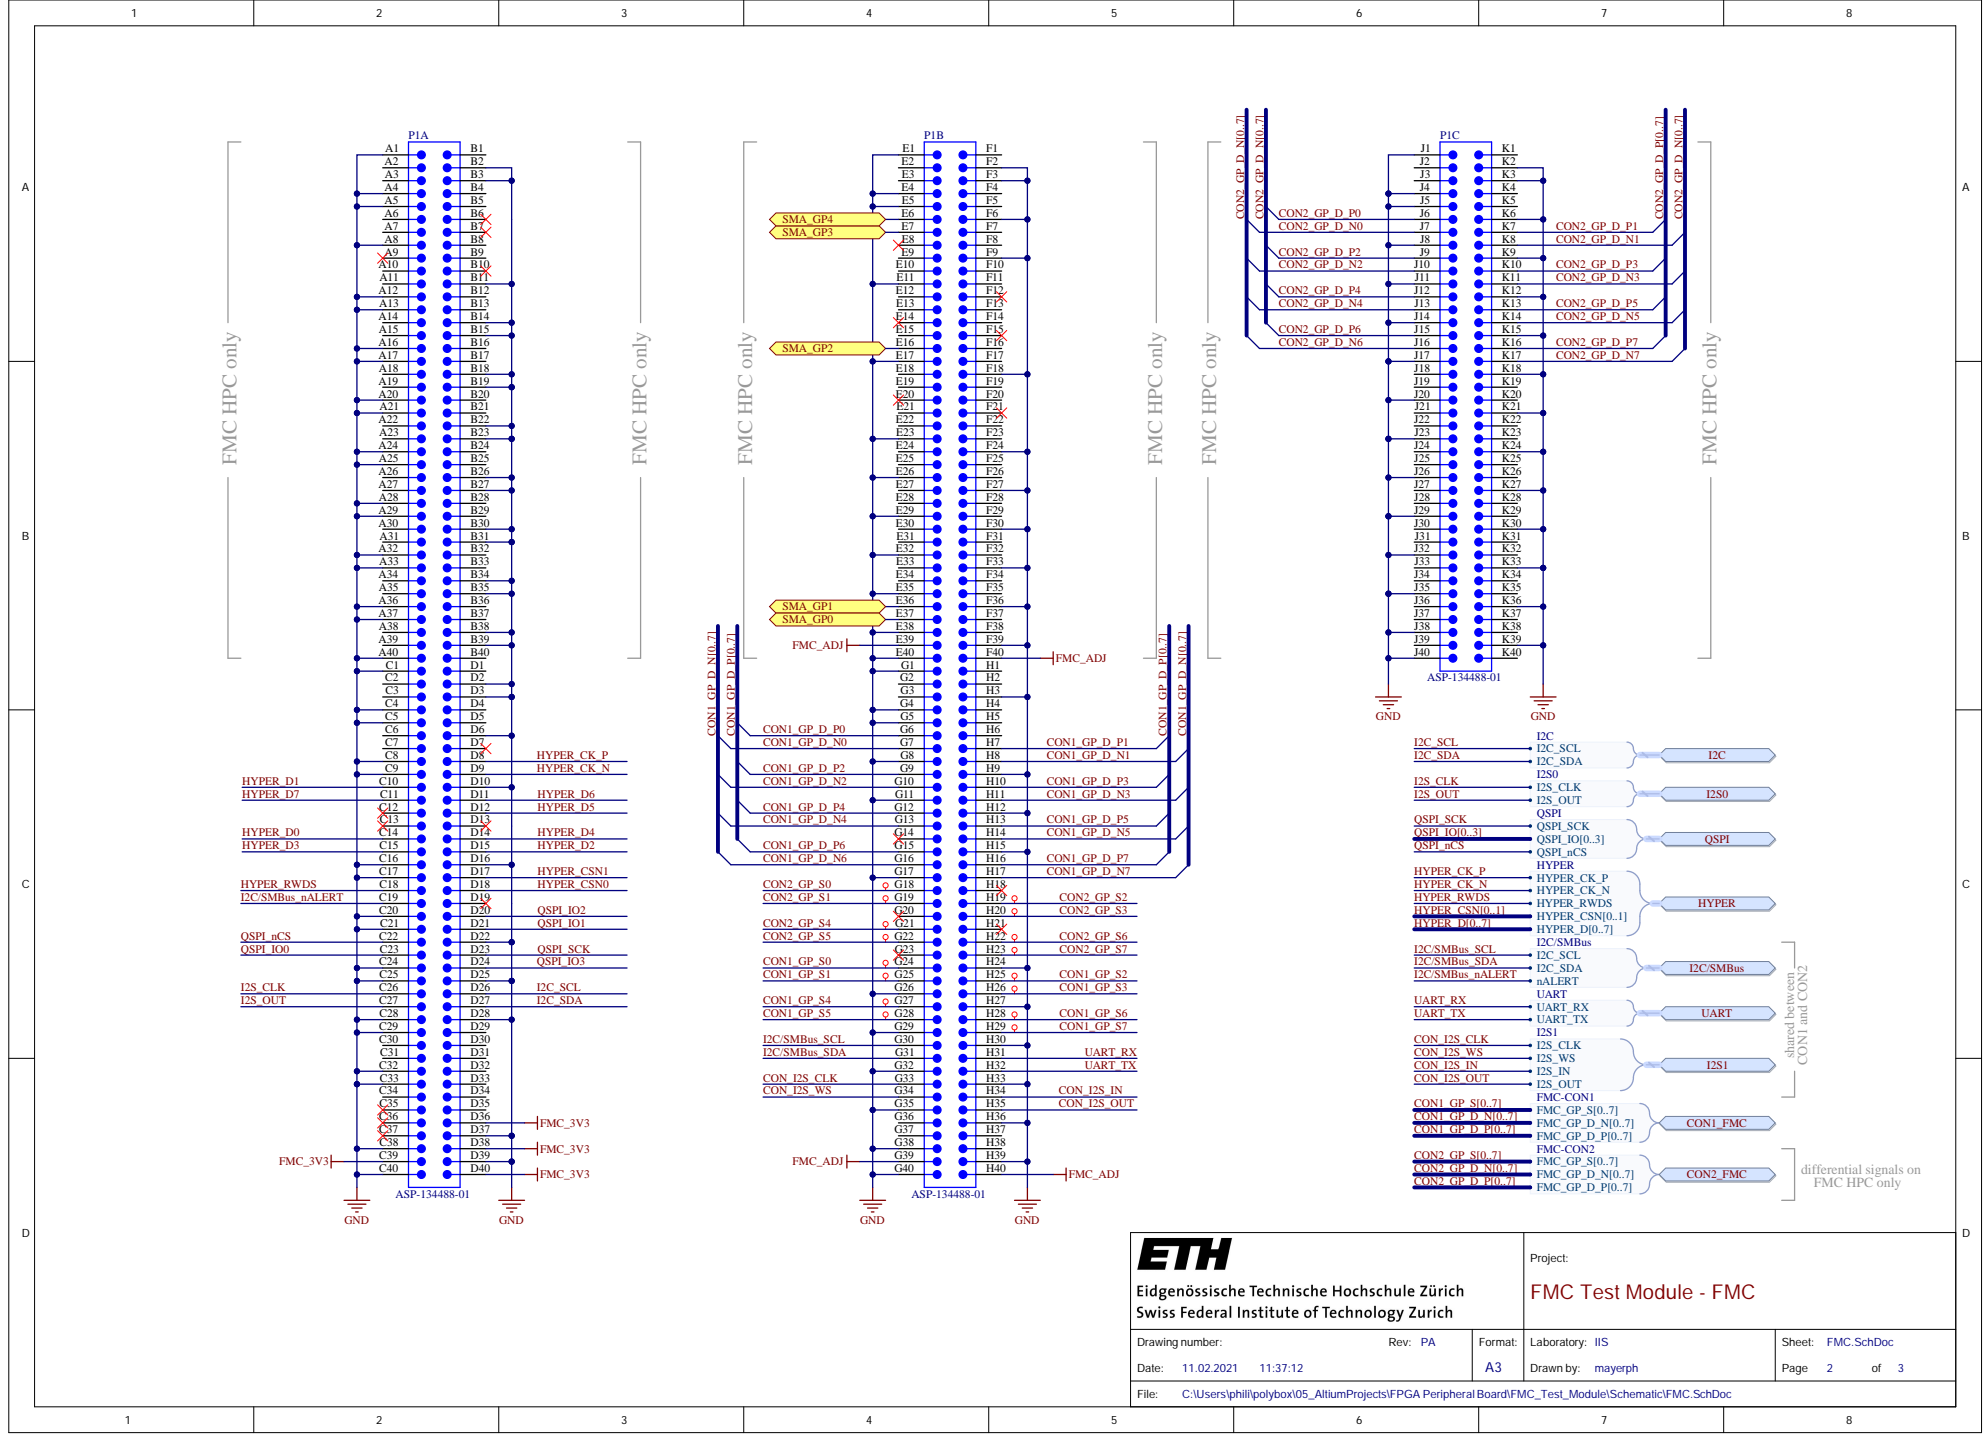
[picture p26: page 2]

K3
K4

CON1 and CON2 differential signals on FMC HPC only

Project: FMC T e st Mo d ule - FMC

Drawin g n umb er: 1 1 | Forma t: | L a b oratory: IIS Drawn by: | Sh eet: FMC.SchDoc Page 2 of 3

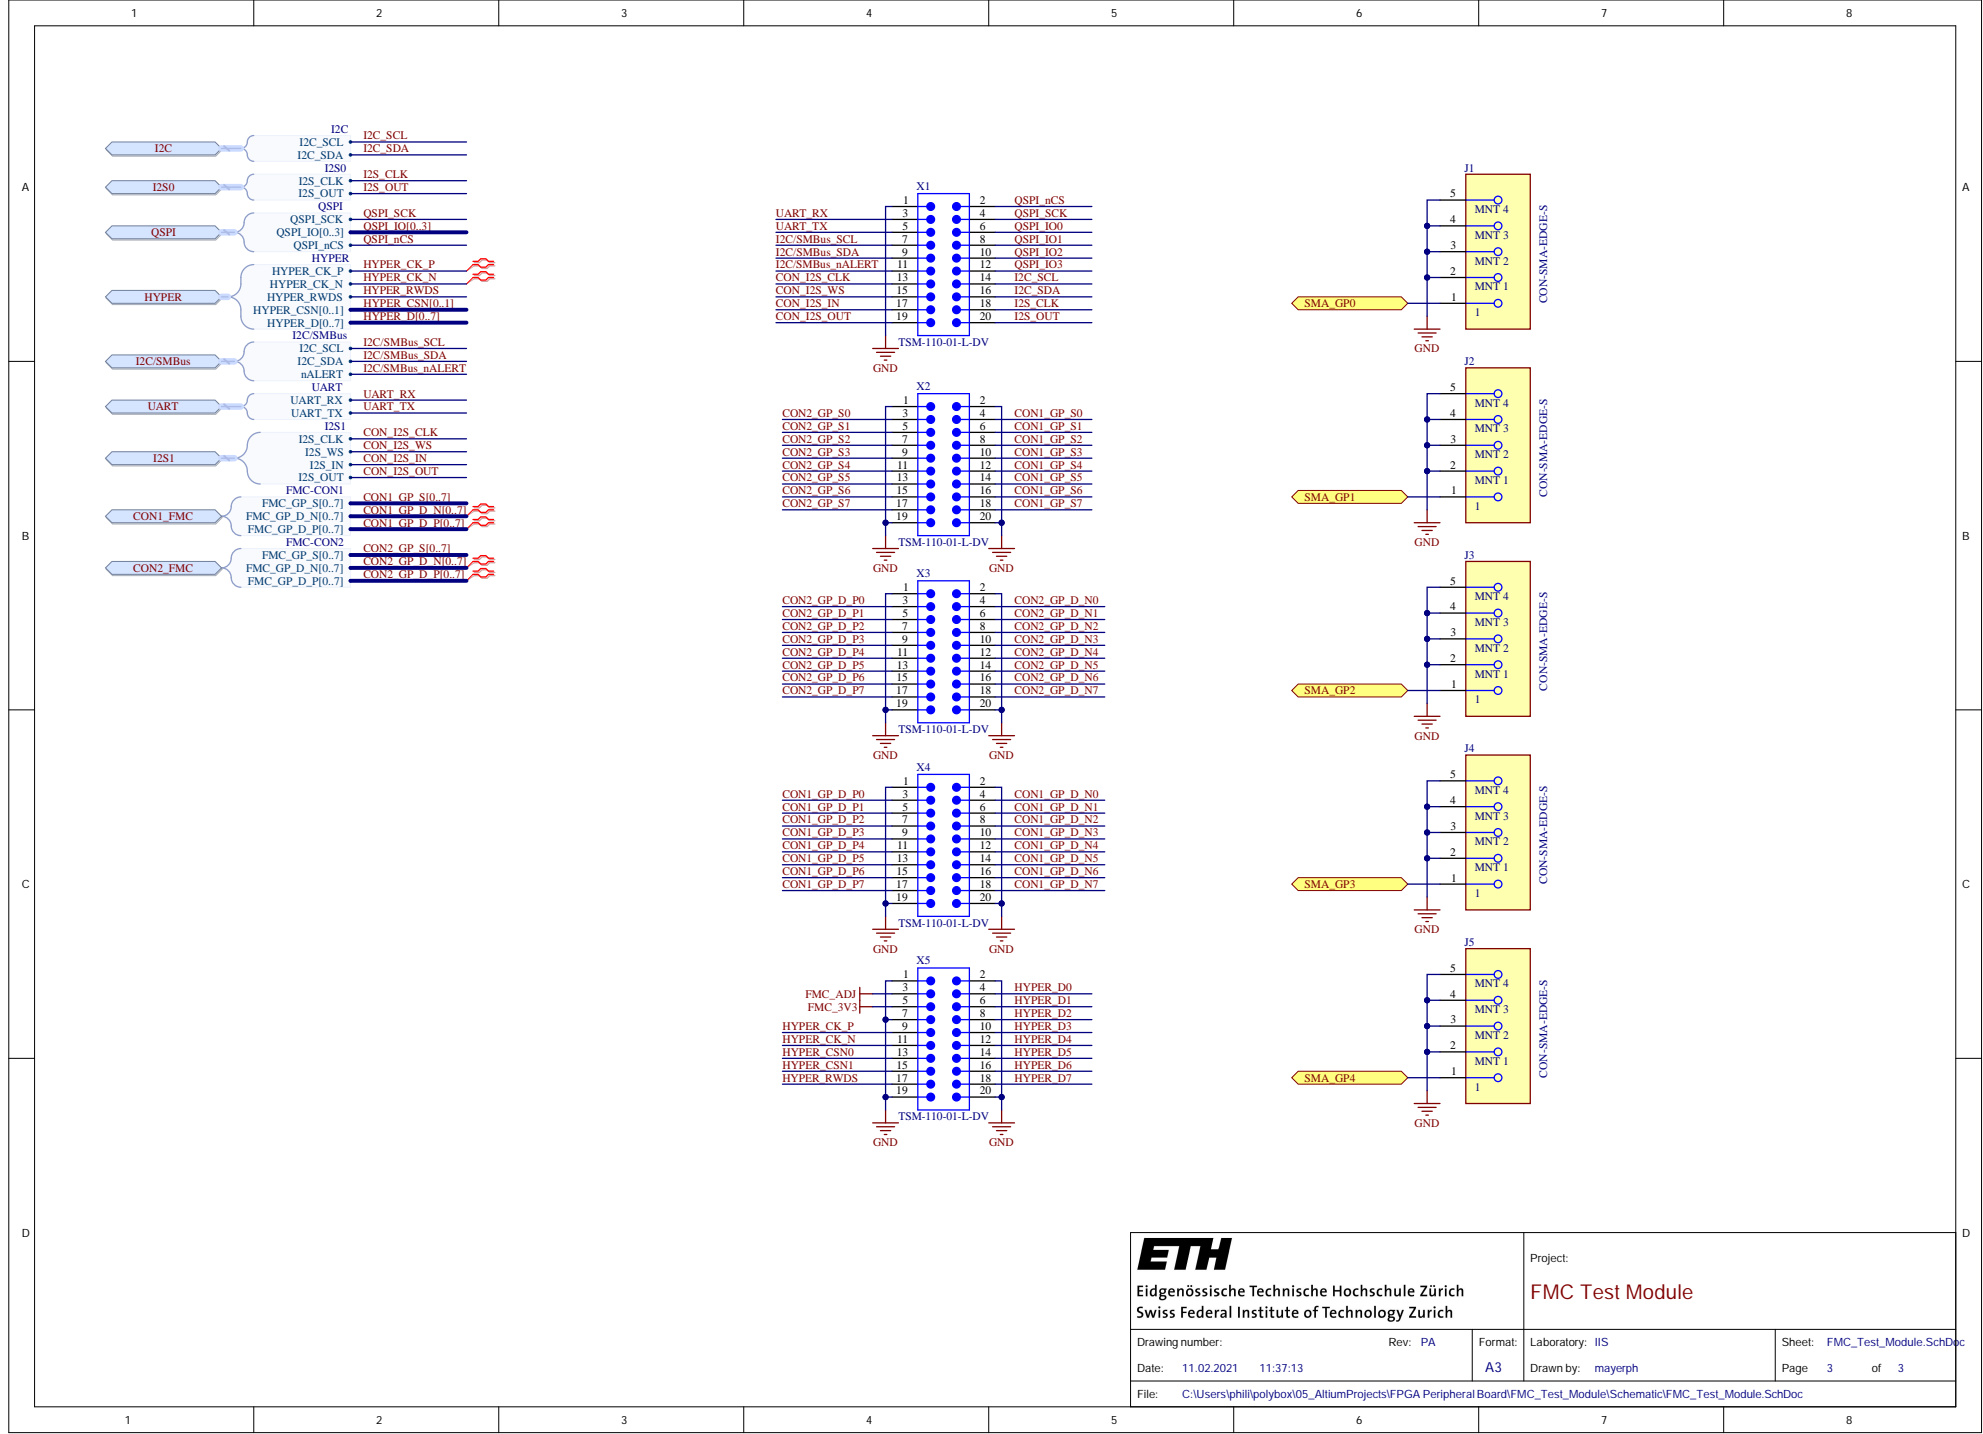
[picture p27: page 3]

Project: FMC T e st Mo d ule

Drawin g n umb er: 1 1 | Forma t: | L a b oratory: IIS Drawn by: | Sh eet: FMC_Test_Mo d ule.SchDoc Page 3 of 3

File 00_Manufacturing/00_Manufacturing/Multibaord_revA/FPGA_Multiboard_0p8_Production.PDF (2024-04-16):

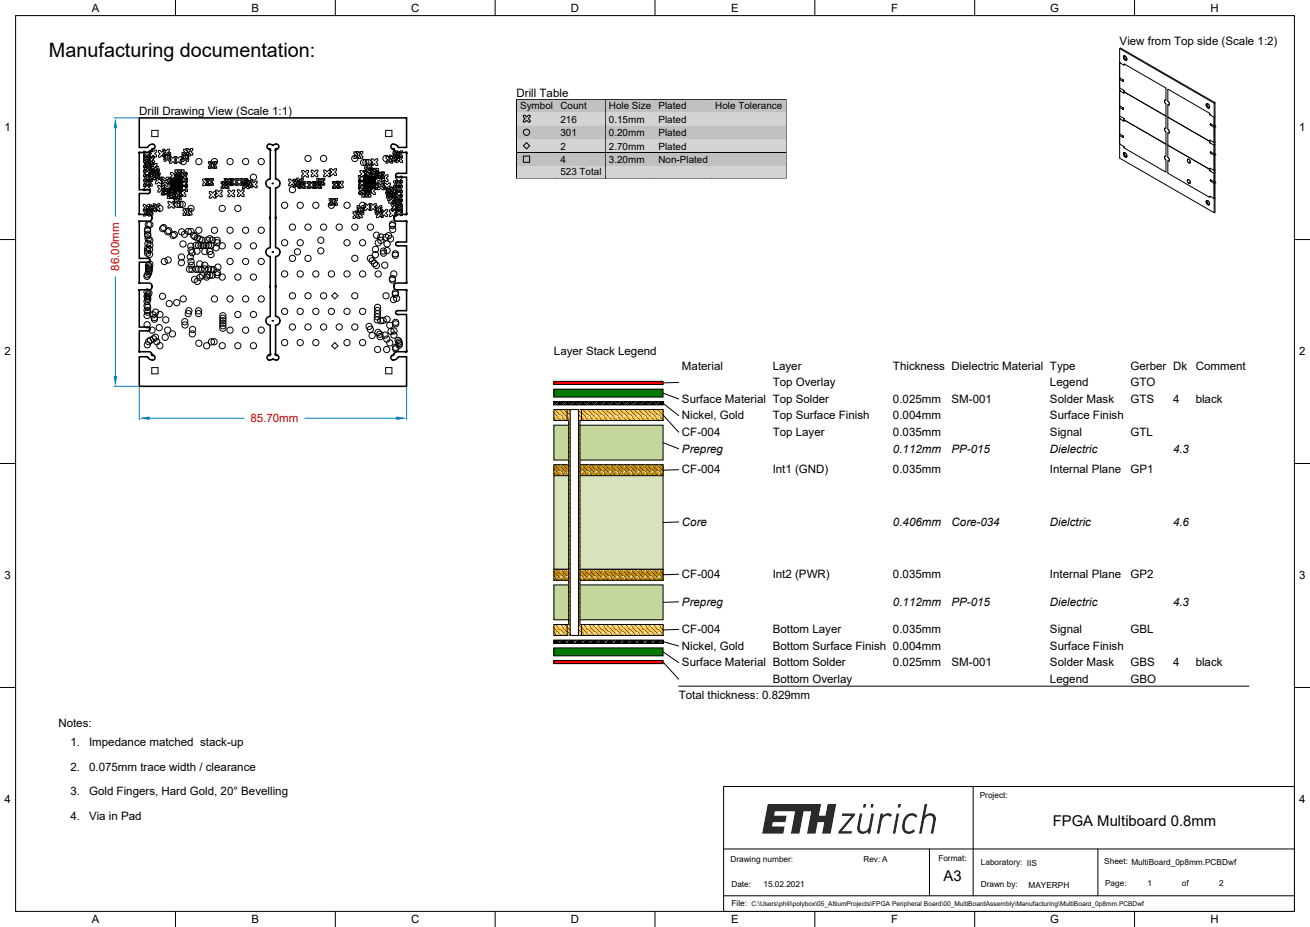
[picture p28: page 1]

View from Top side (Scale 1:2)

Symbol | Count | Hole Size | Plated | Hole Tolerance

Drill Drawing View (Scale 1:1)

216 | 0.15mm | Plated
301 | 0.20mm | Plated
2 | 2.70mm | Plated
4 | 3.20mm | Non-Plated
523 Total

Notes:
1. Impedance matched stack-up

3. Gold Fingers, Hard Gold, 20° Bevelling

Project: FPGA Multiboard 0.8mm

Drawing number: Rev: A Date: 15.02.2021 | Format: | Laboratory: IIS Drawn by: MAYERPH | Sheet: MultiBoard_0p8mm.PCBDwf of A3 Page: 1 2

File:
C:\Users\phili\polybox\05_AltiumProjects\FPGA Peripheral Board\00_MultiBoardAssembly\Manufacturing\MultiBoard_0p8mm.PCBDwf

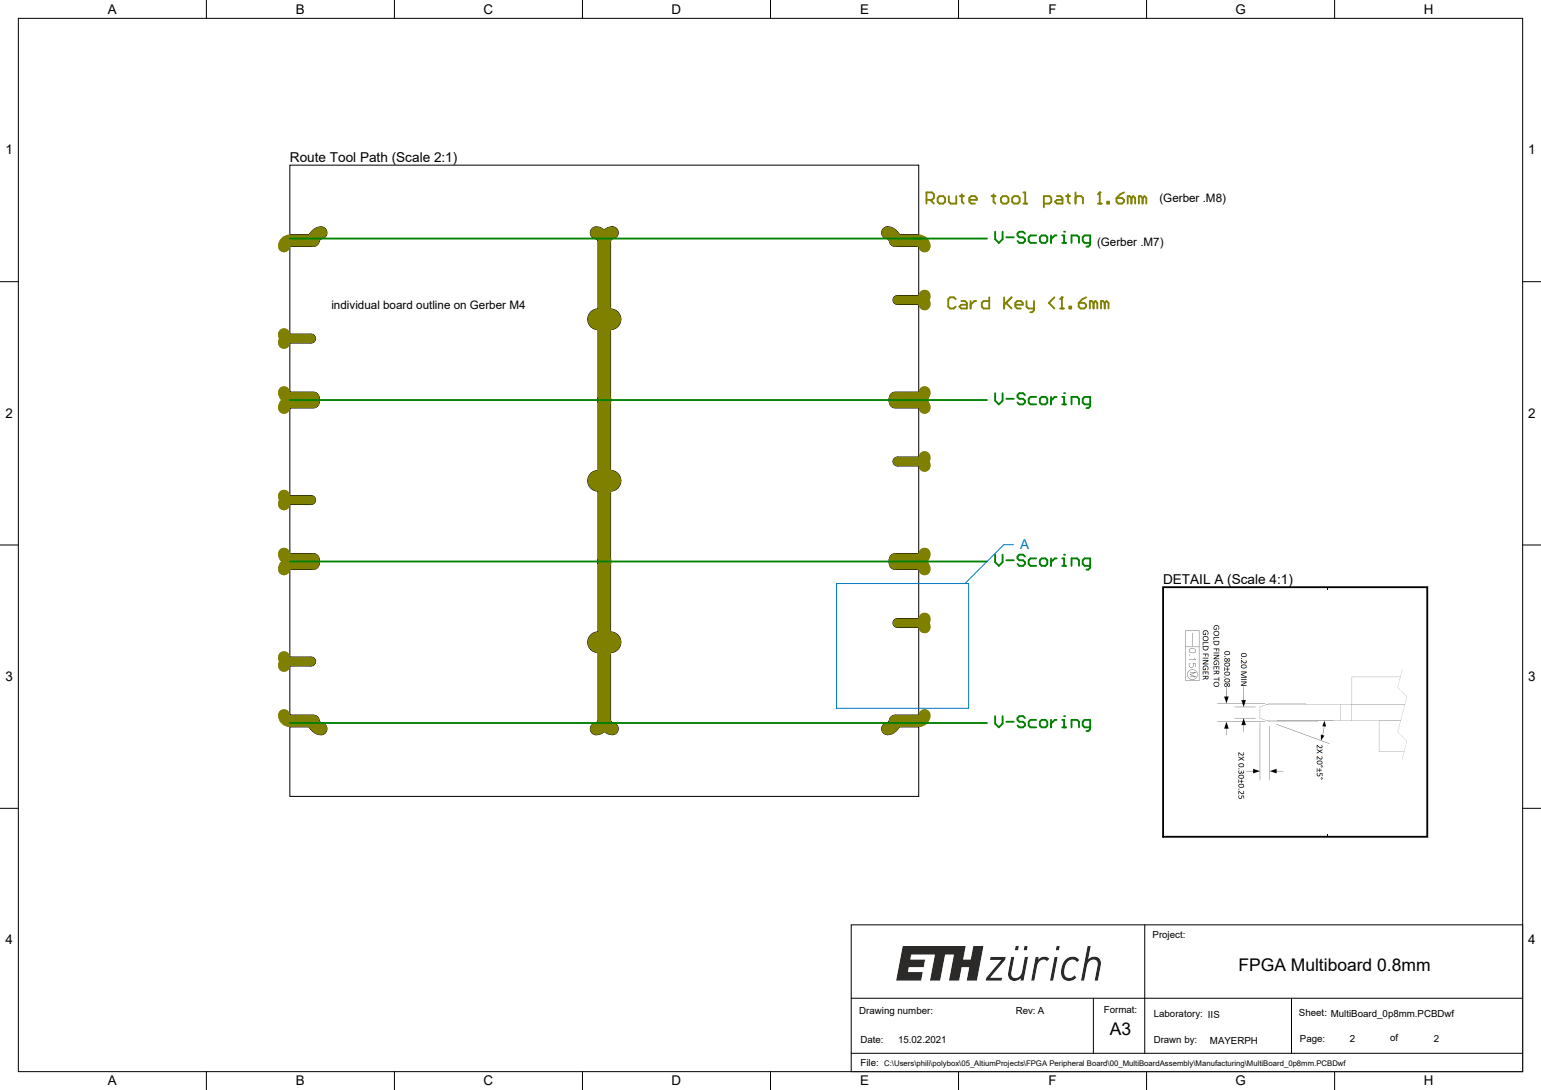
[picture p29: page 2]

Route Tool Path (Scale 2:1)

individual board outline on Gerber M4

Project: FPGA Multiboard 0.8mm

Drawing number: Rev: A Date: 15.02.2021 | Format: | Laboratory: IIS Drawn by: MAYERPH | Sheet: MultiBoard_0p8mm.PCBDwf of A3 Page: 2 2

File:
C:\Users\phili\polybox\05_AltiumProjects\FPGA Peripheral Board\00_MultiBoardAssembly\Manufacturing\MultiBoard_0p8mm.PCBDwf

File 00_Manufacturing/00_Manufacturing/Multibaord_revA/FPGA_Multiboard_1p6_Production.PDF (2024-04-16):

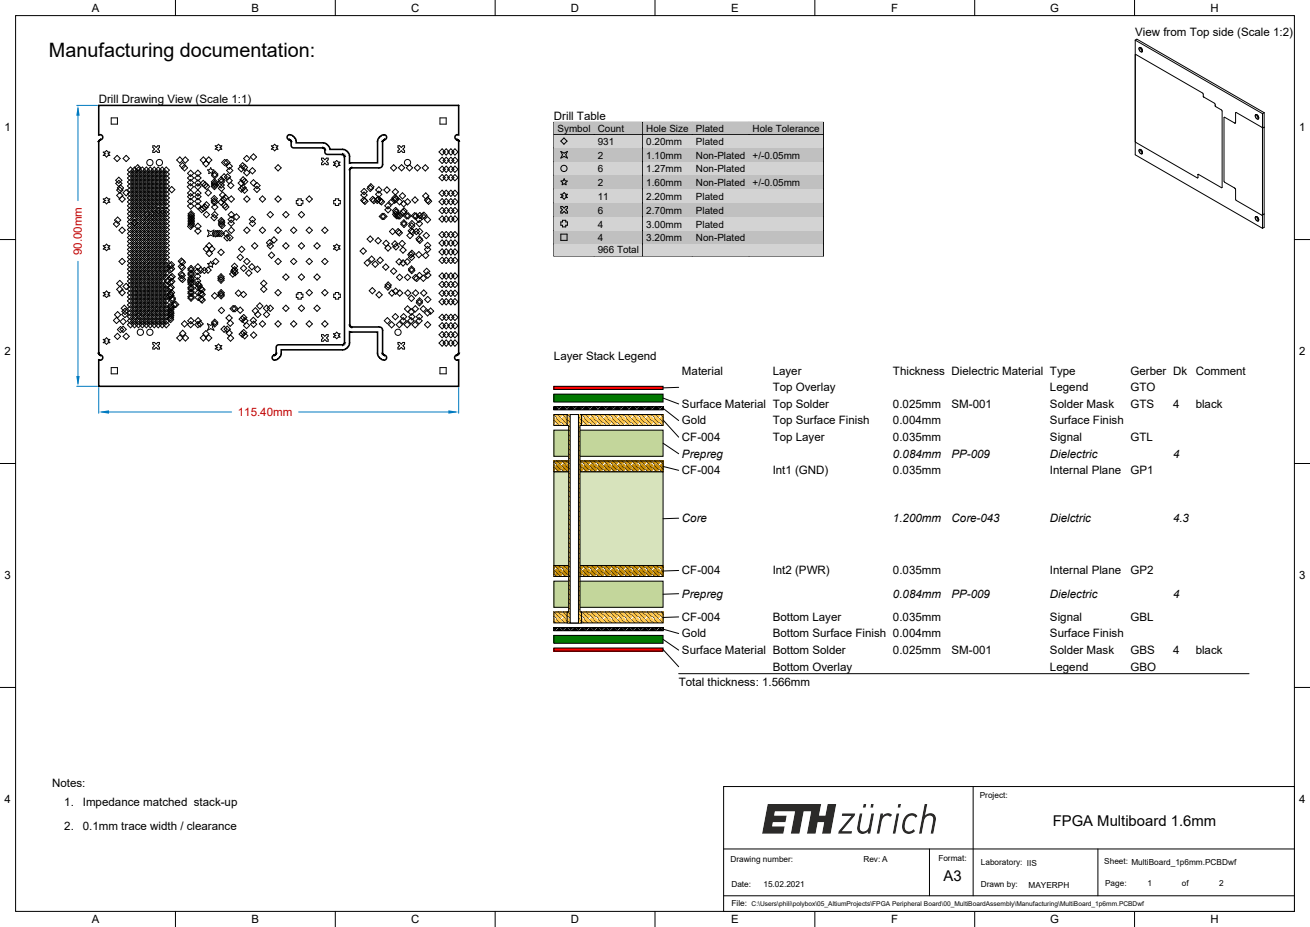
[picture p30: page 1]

View from Top side (Scale 1:2)

Drill Drawing View (Scale 1:1)

Symbol | Count | Hole Size | Plated | Hole Tolerance

931 | 0.20mm | Plated
2 | 1.10mm | Non-Plated | +/-0.05mm
6 | 1.27mm | Non-Plated
2 | 1.60mm | Non-Plated | +/-0.05mm
11 | 2.20mm | Plated
6 | 2.70mm | Plated
4 | 3.00mm | Plated
4 | 3.20mm | Non-Plated
966 Total

Notes:
1. Impedance matched stack-up

Project: FPGA Multiboard 1.6mm

Drawing number: Rev: A Date: 15.02.2021 | Format: | Laboratory: IIS Drawn by: MAYERPH | Sheet: MultiBoard_1p6mm.PCBDwf of A3 Page: 1 2

File:
C:\Users\phili\polybox\05_AltiumProjects\FPGA Peripheral Board\00_MultiBoardAssembly\Manufacturing\MultiBoard_1p6mm.PCBDwf

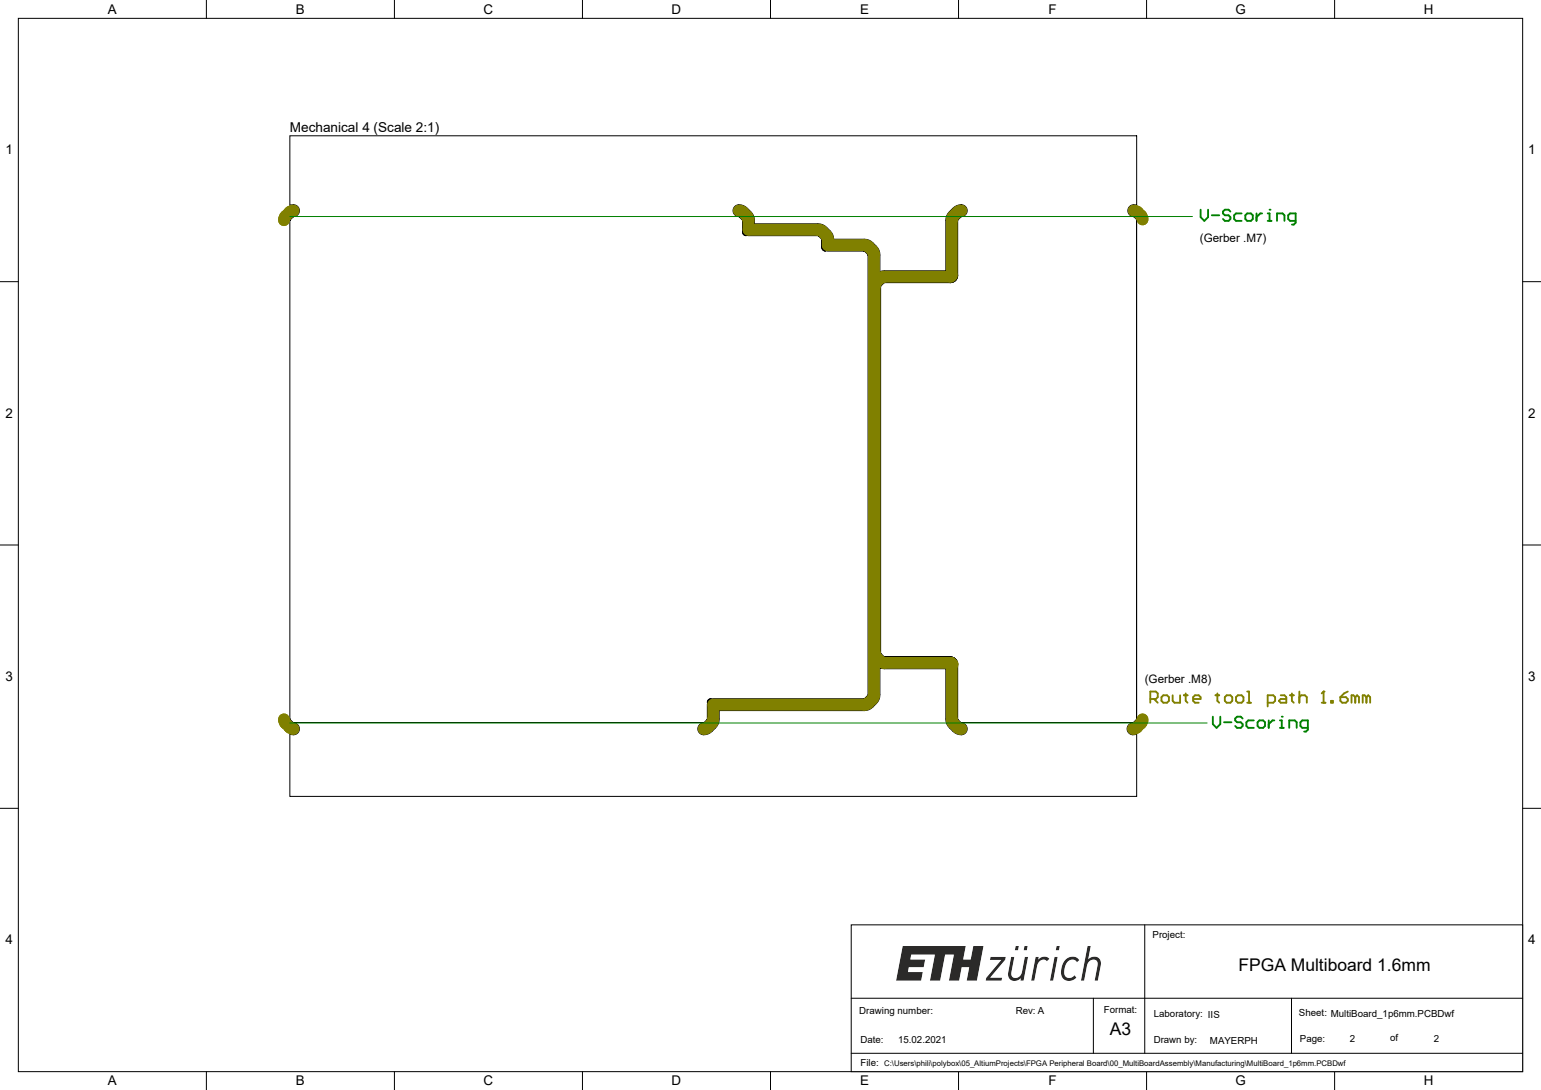
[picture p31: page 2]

Project: FPGA Multiboard 1.6mm

Drawing number: Rev: A Date: 15.02.2021 | Format: | Laboratory: IIS Drawn by: MAYERPH | Sheet: MultiBoard_1p6mm.PCBDwf of A3 Page: 2 2

File:
C:\Users\phili\polybox\05_AltiumProjects\FPGA Peripheral Board\00_MultiBoardAssembly\Manufacturing\MultiBoard_1p6mm.PCBDwf

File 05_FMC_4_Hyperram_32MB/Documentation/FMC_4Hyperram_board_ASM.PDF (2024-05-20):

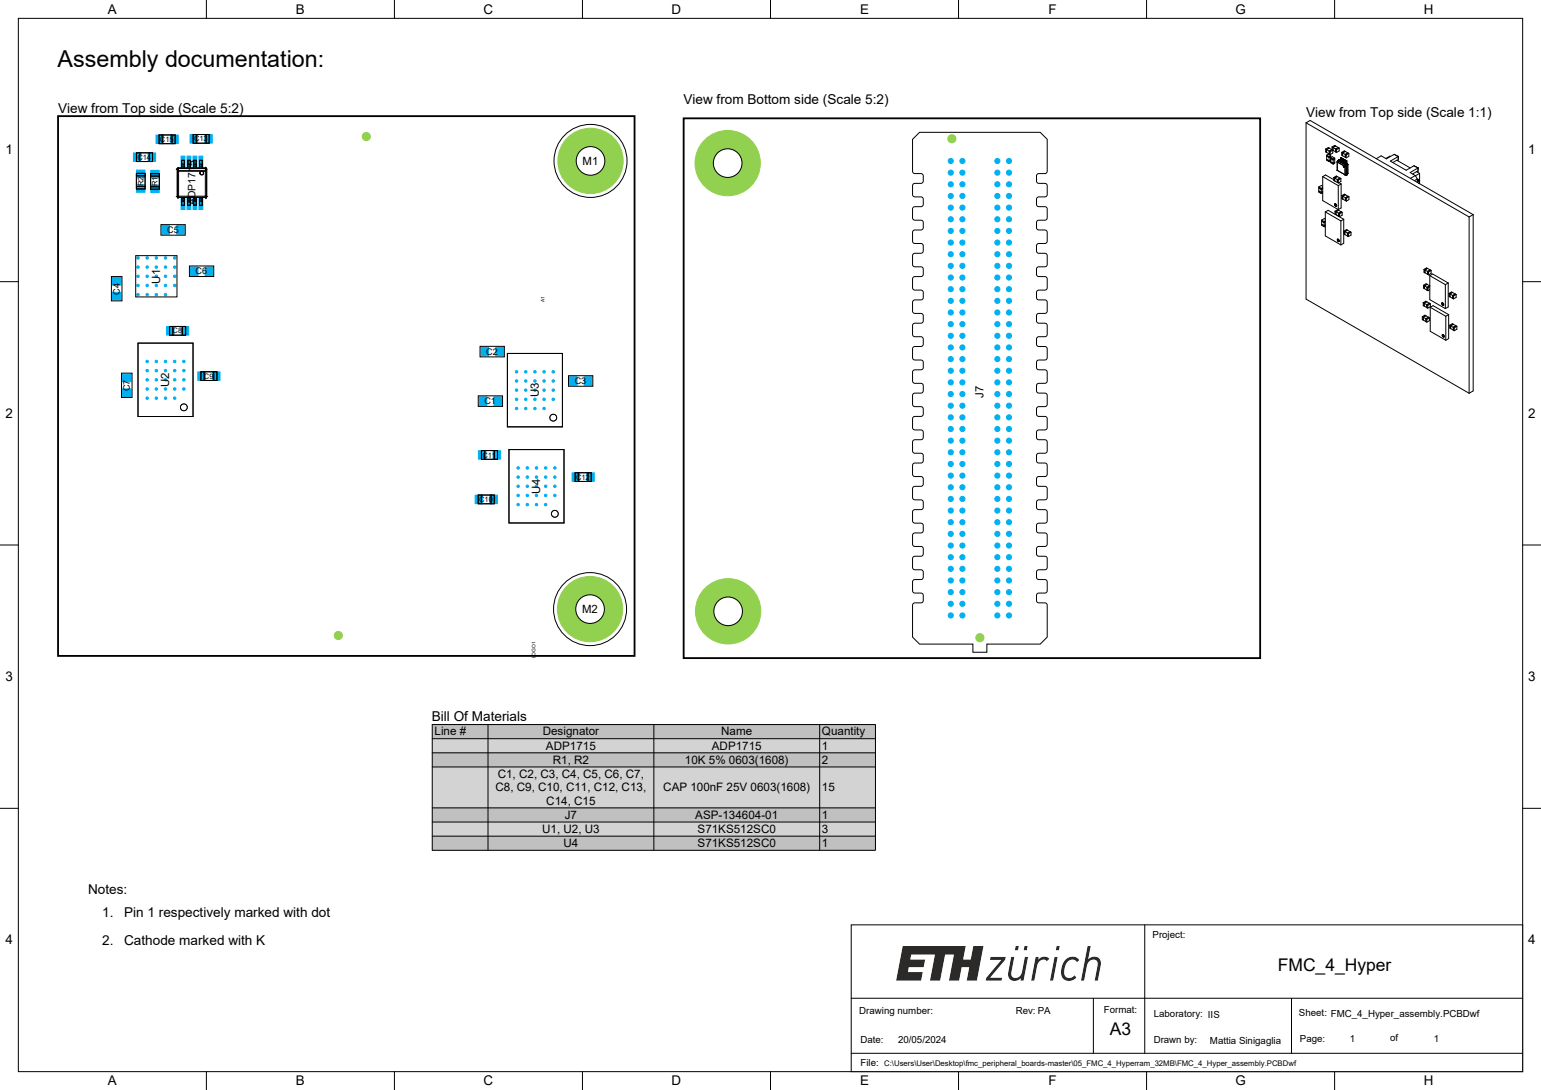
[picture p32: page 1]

View from Bottom side (Scale 5:2)

View from Top side (Scale 5:2)

View from Top side (Scale 1:1)

Line # | Designator | Name | Quantity

ADP1715 | ADP1715 | 1
R1, R2 | 10K 5% 0603(1608) | 2

C1, C2, C3, C4, C5, C6, C7, C8, C9, C10, C11, C12, C13, C14, C15 | CAP 100nF 25V 0603(1608) | 15

J7 | ASP-134604-01 | 1
U1, U2, U3 | S71KS512SC0 | 3
U4 | S71KS512SC0 | 1

Notes:
1. Pin 1 respectively marked with dot

Project: FMC_4_Hyper

Drawing number: Rev: PA Date: 20/05/2024 | Format: | Laboratory: IIS Drawn by: Mattia Sinigaglia | Sheet: FMC_4_Hyper_assembly.PCBDwf of A3 Page: 1 1

File:
C:\Users\User\Desktop\fmc_peripheral_boards-master\05_FMC_4_Hyperram_32MB\FMC_4_Hyper_assembly.PCBDwf

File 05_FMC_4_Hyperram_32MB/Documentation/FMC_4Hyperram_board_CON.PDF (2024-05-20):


View from Top side (Scale 5:2)

View from Top side (Scale 1:1)

FMC | U1 | U2
D24 | CSN | -

C19 | RSTN | RSTN
C23 | CKN | CKN
C22 | CKP | CKP
C26 | RWDS | RWDS
D11 | D0 | D0
D12 | D1 | D1
D14 | D2 | D2
D15 | D3 | D3
C10 | D4 | D4

C14 | D6 | D6
C15 | D7 | D7

FMC | U3 | U4
G25 | CSN | -
G24 | - | CSN
G27 | RSTN | RSTN
G7 | CKN | CKN
G6 | CKP | CKP
G15 | RWDS | RWDS
G13 | D0 | D0
G12 | D1 | D1
G10 | D2 | D2
G9 | D3 | D3
G18 | D4 | D4
G19 | D5 | D5
G21 | D6 | D6
G22 | D7 | D7

Project: uSD Card Module

Drawing number: Rev: PA Date: 20/05/2024 | Format: | Laboratory: IIS Drawn by: MAYERPH | Sheet: FMC_4_Hyper_connectors.PCBDwf of A3 Page: 1 1

File:
C:\Users\User\Desktop\fmc_peripheral_boards-master\05_FMC_4_Hyperram_32MB\FMC_4_Hyper_connectors.PCBDwf

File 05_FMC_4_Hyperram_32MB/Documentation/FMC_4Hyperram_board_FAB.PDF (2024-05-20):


Drill Drawing View (Scale 2:1)

View from Top side (Scale 1:1)

Symbol | Count | Hole Size | Plated | Hole Tolerance

158 | 0.30mm | Plated
2 | 1.27mm | Non-Plated
2 | 3.20mm | Plated
162 Total

Project: uSD Card Module

Drawing number: Rev: PA Date: 20/05/2024 | Format: | Laboratory: IIS Drawn by: MAYERPH | Sheet: FMC_4_Hyper_fabrication.PCBDwf of A3 Page: 1 1

File:
C:\Users\User\Desktop\fmc_peripheral_boards-master\05_FMC_4_Hyperram_32MB\FMC_4_Hyper_fabrication.PCBDwf

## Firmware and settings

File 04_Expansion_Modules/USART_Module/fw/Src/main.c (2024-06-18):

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
/* Includes ------------------------------------------------------------------*/
#include "main.h"

/* USER CODE BEGIN Includes */
#include "string.h"

/* USER CODE END Includes */

/* USER CODE BEGIN PD */
#define BUFFER_SIZE 16

#define SIZE 10

/* USER CODE END PD */

SMBUS_HandleTypeDef hsmbus1;

SPI_HandleTypeDef hspi1;

TIM_HandleTypeDef htim1;
TIM_HandleTypeDef htim2;

UART_HandleTypeDef huart1;
UART_HandleTypeDef huart2;

/* USER CODE BEGIN PV */
uint8_t tx_buffer[BUFFER_SIZE];
uint8_t rx_buffer[BUFFER_SIZE];

uint8_t st_buffer[SIZE]={'S','T','M',' ','f','u','l','l','\n'};
uint8_t pulp_buffer[SIZE]={'P','U','L','P',' ','f','u','l','l','\n'};

/* USER CODE END PV */

void SystemClock_Config(void);
static void MX_GPIO_Init(void);
static void MX_I2C1_SMBUS_Init(void);
static void MX_SPI1_Init(void);
static void MX_TIM1_Init(void);
static void MX_TIM2_Init(void);
static void MX_USART1_UART_Init(void);
static void MX_USART2_UART_Init(void);
/**
  * @brief  The application entry point.
  * @retval int
  */
int main(void)
{
  /* MCU Configuration--------------------------------------------------------*/

  /* Reset of all peripherals, Initializes the Flash interface and the Systick. */
  HAL_Init();

  /* Configure the system clock */
  SystemClock_Config();

  /* Initialize all configured peripherals */
  MX_GPIO_Init();
  MX_I2C1_SMBUS_Init();
  MX_SPI1_Init();
  MX_TIM1_Init();
  MX_TIM2_Init();
  MX_USART1_UART_Init();
  MX_USART2_UART_Init();
  /* USER CODE BEGIN 2 */
  uint8_t i=0;
  uint8_t error=0;
  memset(rx_buffer, 0, BUFFER_SIZE);
  memset(tx_buffer, 0, BUFFER_SIZE);

  /* USER CODE END 2 */

  /* Infinite loop */
  /* USER CODE BEGIN WHILE */
  //HAL_UART_Transmit(&huart1, tx_buffer, BUFFER_SIZE, 1000);

  while (1)
  {
    /* USER CODE END WHILE */

    /* USER CODE BEGIN 3 */
	while(i<BUFFER_SIZE)
	{
		if(HAL_GPIO_ReadPin(GPIOA, GPIO_PIN_12)==1)
		{
			HAL_UART_Transmit(&huart2, st_buffer, SIZE, 1000);
			HAL_Delay(10);
			HAL_UART_Receive(&huart1, rx_buffer+i, 1, 10);
			i++;
			HAL_Delay(1);
		}
	}

	i=0;
	while(i<BUFFER_SIZE)
	{
		//if(tx_buffer[i]!=rx_buffer[i]) error++;
		HAL_UART_Transmit(&huart1, rx_buffer+i, 1, 1000);
		i++;
		if(HAL_GPIO_ReadPin(GPIOA, GPIO_PIN_11)==1) HAL_UART_Transmit(&huart2, pulp_buffer, SIZE, 1000);
	}

	HAL_UART_Transmit(&huart1, rx_buffer, BUFFER_SIZE, 1000);

	while(1)
	{
		HAL_GPIO_TogglePin(GPIOB, GPIO_PIN_1);
		HAL_Delay(100);
	}
  }
  /* USER CODE END 3 */
}

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


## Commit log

2024-05-17 Update README (#1)
    [Ethernet_Module_BOM.xlsx]
2024-05-20 Update FMC_4_Hyperram_32MB design (#2)
    [FMC and Power.SchDoc, FMC_4Hyperram_board.PrjPcb, FMC_4Hyperram_board.SchDoc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]
2024-05-20 update Ethernet module (#3)
    [Ethernet.SchDoc, Ethernet_Module.PrjPcb, connector.SchDoc]

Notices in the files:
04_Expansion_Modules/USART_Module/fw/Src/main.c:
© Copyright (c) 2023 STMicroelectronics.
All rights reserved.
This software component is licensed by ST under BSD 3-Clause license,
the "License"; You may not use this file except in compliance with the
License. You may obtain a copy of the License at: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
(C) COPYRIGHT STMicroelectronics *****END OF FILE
